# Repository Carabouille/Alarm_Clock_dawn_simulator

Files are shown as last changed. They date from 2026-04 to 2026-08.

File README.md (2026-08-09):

# Alarm_Clock_dawn_simulator
Hello, I'm Carabouille, a French guy who loves tech and hardware, and this is my GitHub to present you my project for Fallout!
I'm gonna present you my alarm clock with dawn simulator feature!

AND see just how beautiful it is !!! Yeah I know I did a great job you can tell me ^^

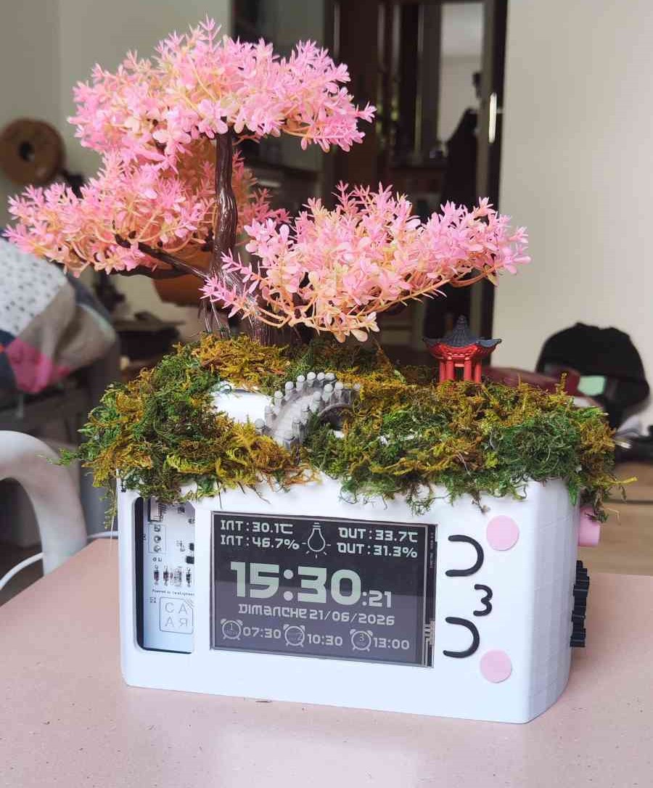
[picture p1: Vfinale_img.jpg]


And to see how it works in details you can watch the video that I did on my alarm clock : (CLICK ON MY AWESOME FACE !)

Clicl here ! (https://youtube.com/shorts/Zd3teZ0syxg)

# The idea 
I often have trouble waking up with my phone alarm. I often feel that I'm tired even though I slept a lot. And this is for a very simple reason: our brain is not a machine, he can't wake up so fast. He works on cycles. And our phone alarm gets him off very fast during this cycle. A better way to wake up more naturally is with the solar light (but the night I close the rolling shutter for the cold). So a solution to this issue is to use an alarm clocker with a dawn simulator feature to increase the brightness of the room over time to wake up your brain gently, but problem : Tis type of alarm clocks is really expensive (over 100 euros), so I told myself that it is the perfect occasion to create my own ALARM CLOCKS WITH A DAWN SIMULATOR!!! And I'm gonna add a lot of features like: 
- local weather
- Indoor temperature / humidity
- Bedside lamp (to read the night)
- Control all the Leds in my bedroom
- and more.....

I really can't wait to build my project, develop my skills and learn so much! I'm gonna give the best version of myself to be proud of my alarm clocks and I also hope that I will have the chance to go to Shenzen to meet other hardware fans! Kind regards, your French friend, Florian "Carabouille" CHARLES :))

# Zine page 
The better way to describe my project is with a poster who talks about it! 
I'm not a good designer, but I think that I made a good poster

ET VOILA : 

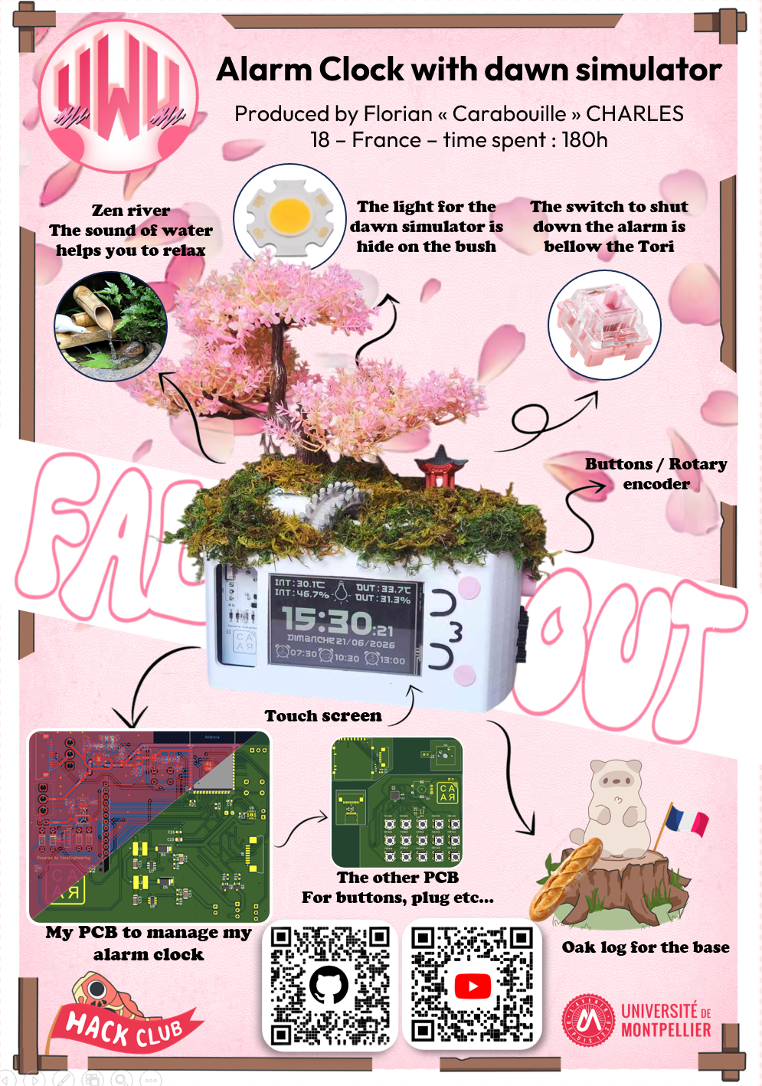
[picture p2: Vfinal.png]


The design idea is pretty simple: the alarm clock in the center and some arrows to explain the different parts of the project
I explain here 7 features: 
- The oak log for the base
- All the PCBs
- The touch screen
- The Zen river
- The light for the dawn simulator feature
- The switch on the top
- And the switches and the knob on the side

My favourite color is the pink (hard to guess ^^)
I really love the cherry flower in the background that reminds me of the cherry tree on the top of the alarm.
The UwU logo is everywhere cause with my friends it's a private joke since a few years.
I love the way that the "Fallout" goes behind the box.

Is not perfect of course but for my light skills in design I think it's really nice, I'm proud of it ! 

# CAD 
One of the main parts of my project is the CAD!
For this I used the software Solidworks ( a French soft! COCORICO!)
I'm in a toxic relationship with Solidworks, sometimes I love it, sometimes I hate it...
This software is not easy to use but after some crashes and bugs I finally made a CAD which I'm proud of

So for my project I had to work within certain constraints 

- a specific screen size
- a way to diffuse the light
- a heat sink for the light
- some buttons
- a battery
- a speaker
- a hole for the USB C port

And with all that, I need to find a good idea for design

My first idea was a shape like the giant telescope, like we can see in the American desert.
But I have never obtained a result that I like

So I completely changed my idea to have a Zen garden on the top of my alarm clock
With a tree, plants, and a river!

It looks like this : 

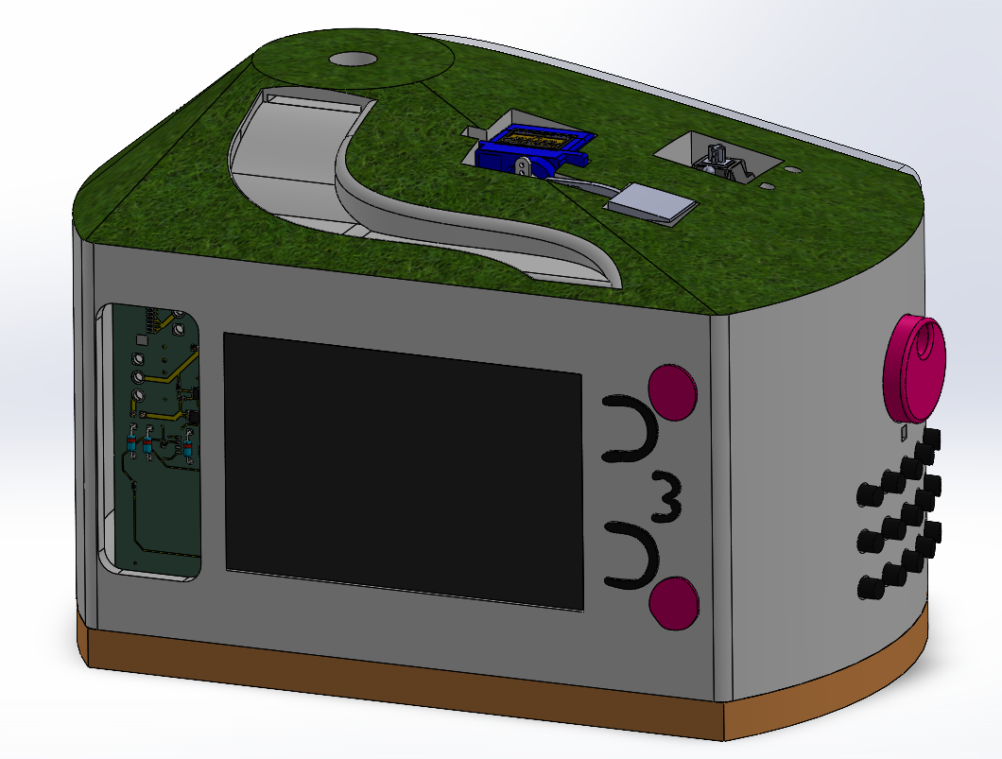
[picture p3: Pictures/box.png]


yes that is not the same as on the zine page,
Solidworks is not really good at rendering

But all the parts are here and I even find it cool! 
I really love that the PCB is not hidden by all the cases, it's cool to see it

On this picture we can see : the screen, the PCB, the UwU logo, the oak log and the buttons on the side

If we move to the top we can see the Zen garden 

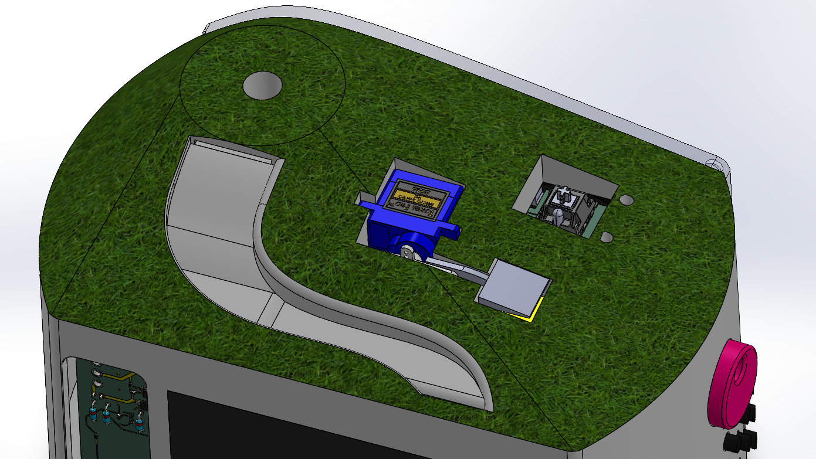
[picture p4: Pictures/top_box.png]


We can see :
- The hole on the top, for the cherry tree
- The river on the front
- The switch to shut down the alarm
- The green is for the artificial moss
- and the servo motor

The servo motor is here to hide the light during the day with moss on it. And when is it the time to turn the light on the servo motor move the piece of plastic with moss on it that hides the light to let the light illuminate the room.
So the light system is invisible during the day!

The servo motor is not hidden by the case cause the moss will recover it.

And on the switch I'll put a little Japanese temple like we can see on the poster.

Let's make the walls transparent to see what is inside the box!

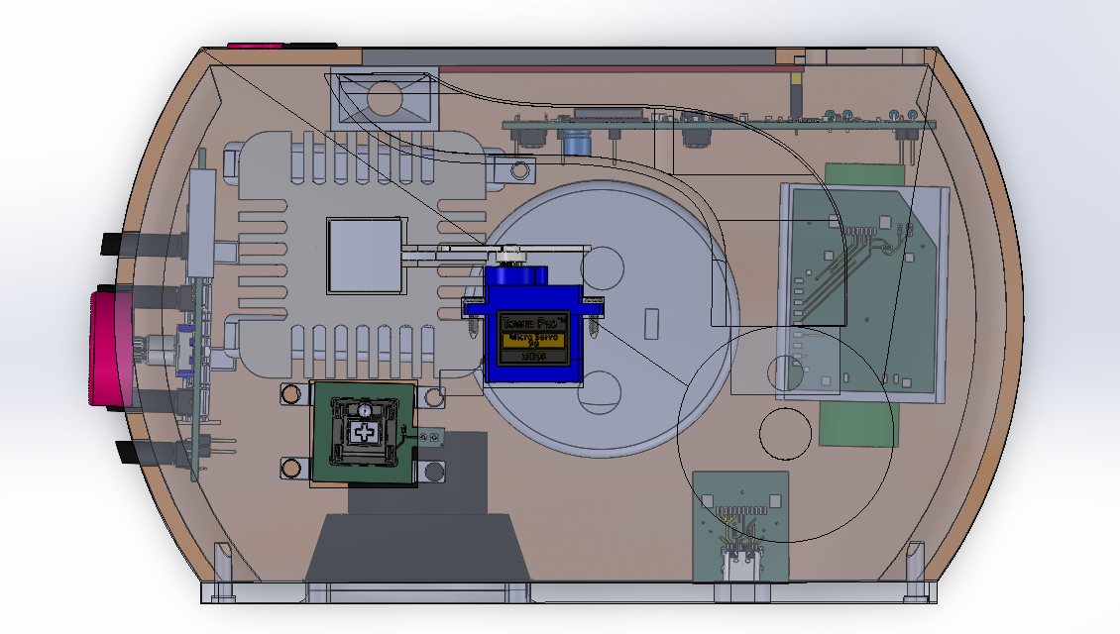
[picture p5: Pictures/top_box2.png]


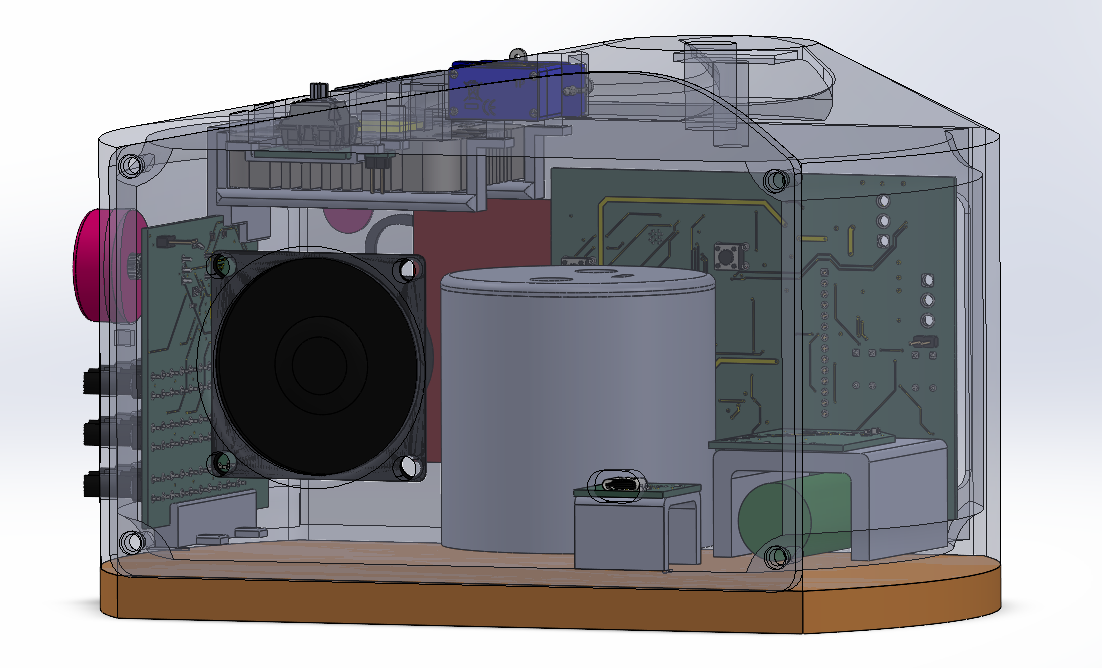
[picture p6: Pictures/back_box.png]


Yes, there are a lot of things inside it! 

We can see well in the first picture the servo motor as we saw earlier
And the light with the heat sink, which is carried by a support with screws to the box
The heat sink is necessary here cause the light needs to be at least a 8W to diffuse a minimum of the light to wake you. 
But the light is also powered on 24V and if you do the calcul

P = U * I

I = P / U

I = 8 / 24 = 0,33 A 

It's a lot for a little LED COB ! It can heat up to more than 100 degrees. With the heat sink, everything will be ok!

If we watch the second picture we can see the other components

Like the speaker, even if the light is supposed to wake you. If you sleep very deeply, good music is necessary to wake up! 
We can see on the left the PCB buttons for all the buttons and the knob. Is linked with the main PCB with a FPC cable.

The huge tank in the middle is for the water of the river. The pump is also inside. The holes are for the pipes.

We can see the USB C port in the bottom right also linked with the main PCB with a FPC cable.

On the right we have the PCB for the SD card. And below it we have our battery.
The battery is just in case that there is a power cut at home, the battery will supply the system until the return of power !

And that's already a lot for a CAD, but I'm really proud of me! I can't wait to print it!

# PCB

OK so now it's the moment to talk about my PCB! And it's a huge part of my project! 
It's only my second PCB so it's not perfect, the first was the macropad.

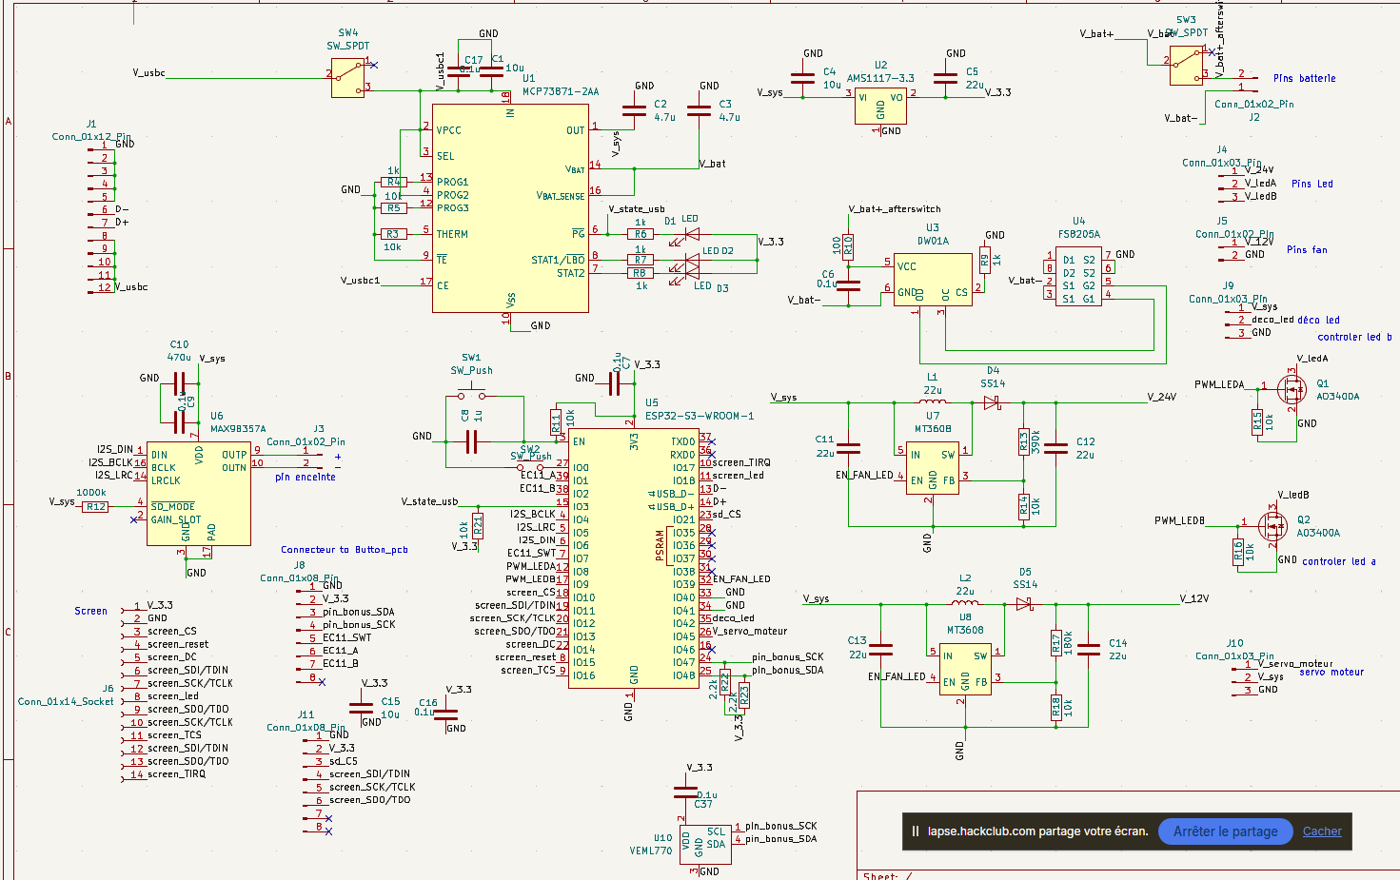
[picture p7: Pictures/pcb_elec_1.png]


This is only the main PCB, and I'm going to describe all the different parts
I'm not gonna describe how I chose the components because it's not really important, but for each component I had to follow the datasheet.

So we can see at the top left the port J1 that brings the power supply from the USB C port on an other PCB.
The power is sent to the first components the MCP73871. This component charge at the same time the battery in 4,2V and supplies the system with the 5V

But 5V is too high for an ESP32, so we need to decrease it to 3,3V with the AMS1117-3.3.

For this project I used an ESP32-S3-WROOM-1 that is very powerful and the WiFi connection will help me to search for the local weather.

For the speaker, we need to use an audio amplifier. I chose to use the MAX98357A, which is very famous for this type of project

I used a DW01A and a FS8205A, this duo of components is for the battery. To avoid overload, deep discharge, and protection from the short circuit.

For the LED and the fan of the heat sink I need 24V and 12V. So I used a 2 MT3608 to increase the voltage.

To control the led I'll use 2 channels of PWM to manage the warm and cold colors of the led.
To do this I'm gonna use a 2 transistors A03400A.

I also use a VEML770 a light sensor to manage the luminosity of the screen.

We also have a lot of connectors for the : 
- Screen
- USB C
- Heat sink
- Led COB
- Led strip (to decorate)
- servo motor
- SD card PCB
- Buttons PCB
- Battery

You can see two footprint for a switch (SW3 & SW4), if you wish to switch off the main power supply or just the battery power supply (!YOU NEED TO PLACE IT ! else the circuit is open)

And after having done the wiring diagram, it's time to root all the components between them! 

This is my final solution:

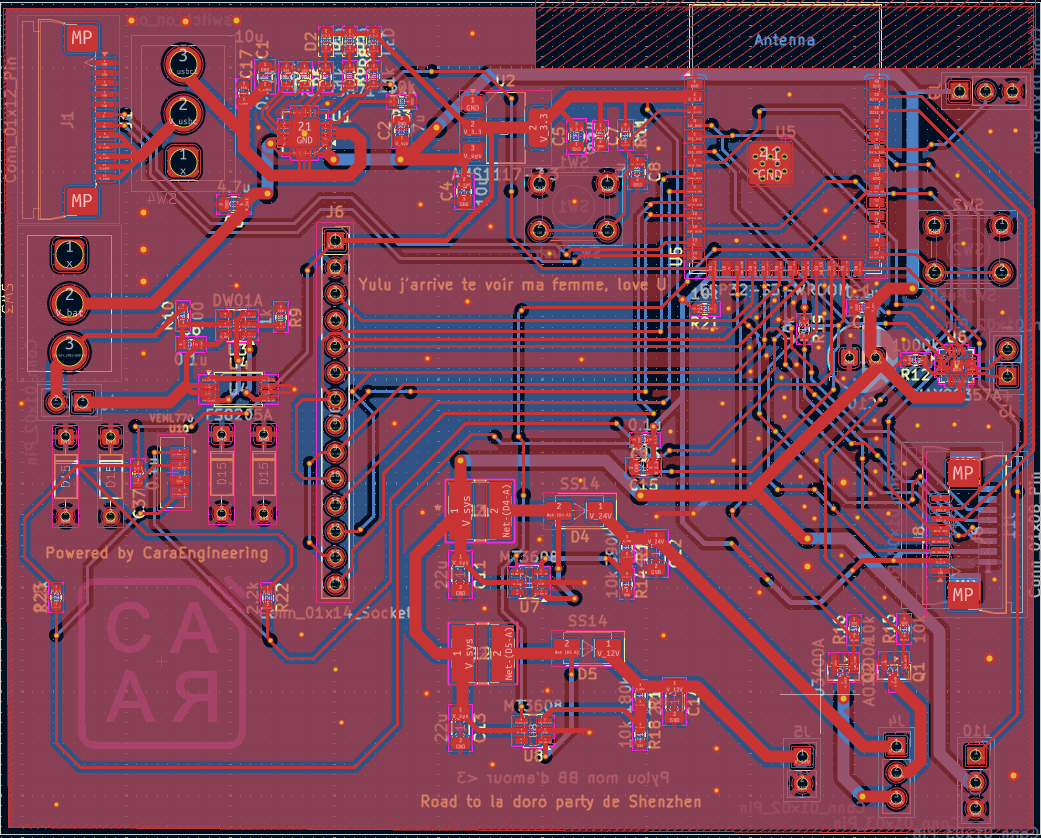
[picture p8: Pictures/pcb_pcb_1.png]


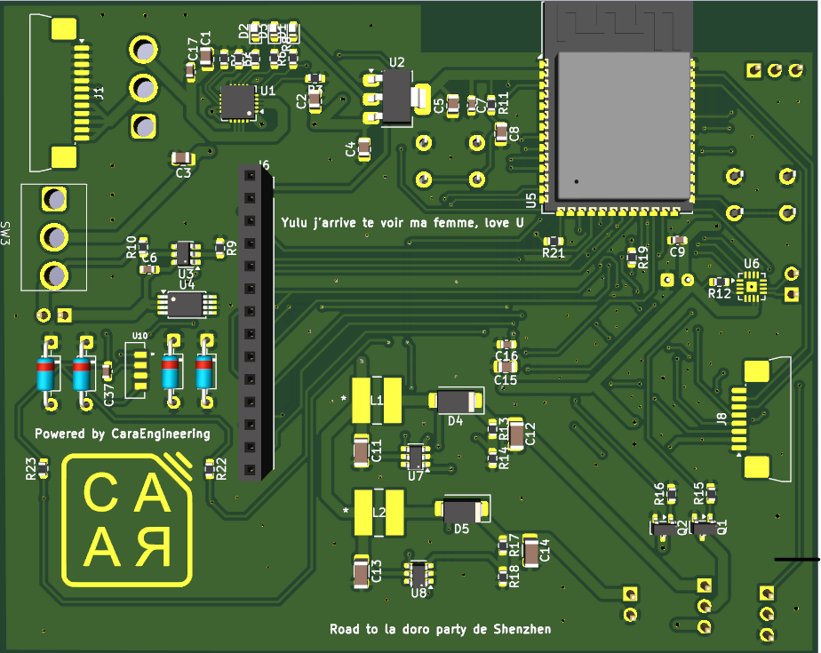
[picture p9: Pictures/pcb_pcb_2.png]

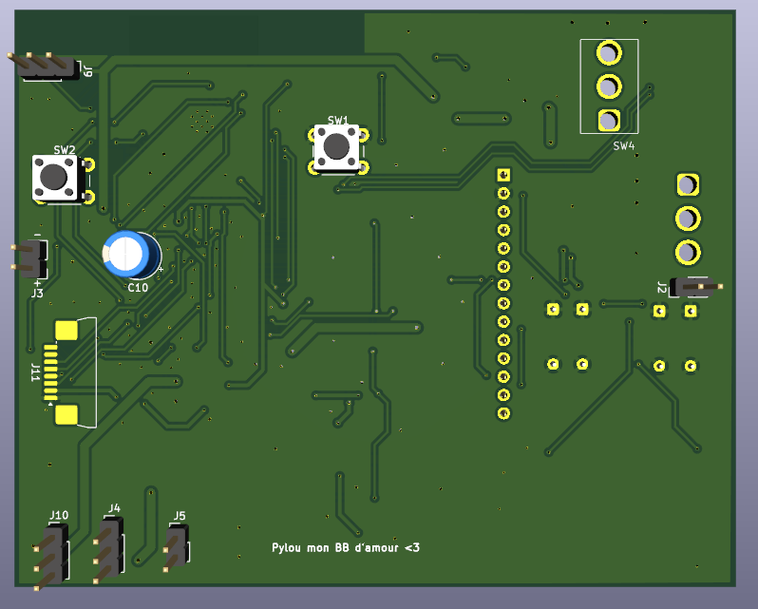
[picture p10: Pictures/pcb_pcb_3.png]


We can see here all the components which I mentioned earlier
I root on 2 faces so it's not too difficult to do it. The main difficulty is to match the footprint with the real component.

And that's all for the main PCB. It's already a lot!

Let's talk about the second PCB, The Buttons PCB!! 

This PCB is simpler than the previous one, it is just a little repetitive with all the buttons 
We can see here the wiring diagram!

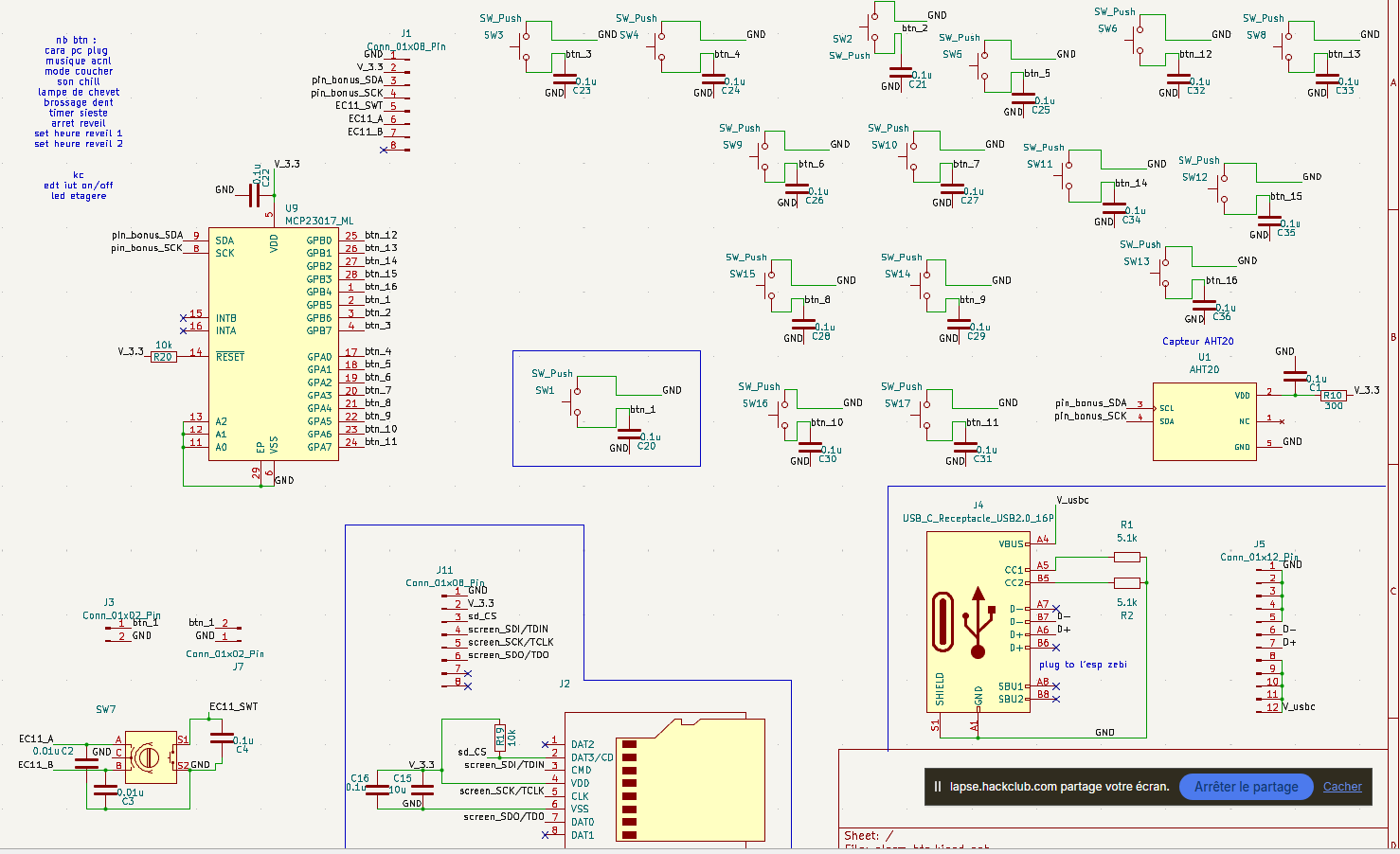
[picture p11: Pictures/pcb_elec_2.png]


You can see here 4 different PCBs separated by the blue lines.
The larger is the PCB with all the buttons and the polar.
Also, I used a MCP23017 to increase the number of pins GPIO of the ESP32 ( I used a lot of buttons ^^) I'll go into detail in the firmware part. 
You can see a capacitor in parallel for each button. It's anti-bounce material. It's very important for a professional project!
I added on this PCB an AHT 20, it's a temperature and humidity sensor.

The little PCB in the middle is for the switch on the top of the box.

The PCB on the bottom is the micro SD port card PCB

and the last is the PCB for the USB C

And after this it's rooting time ! 

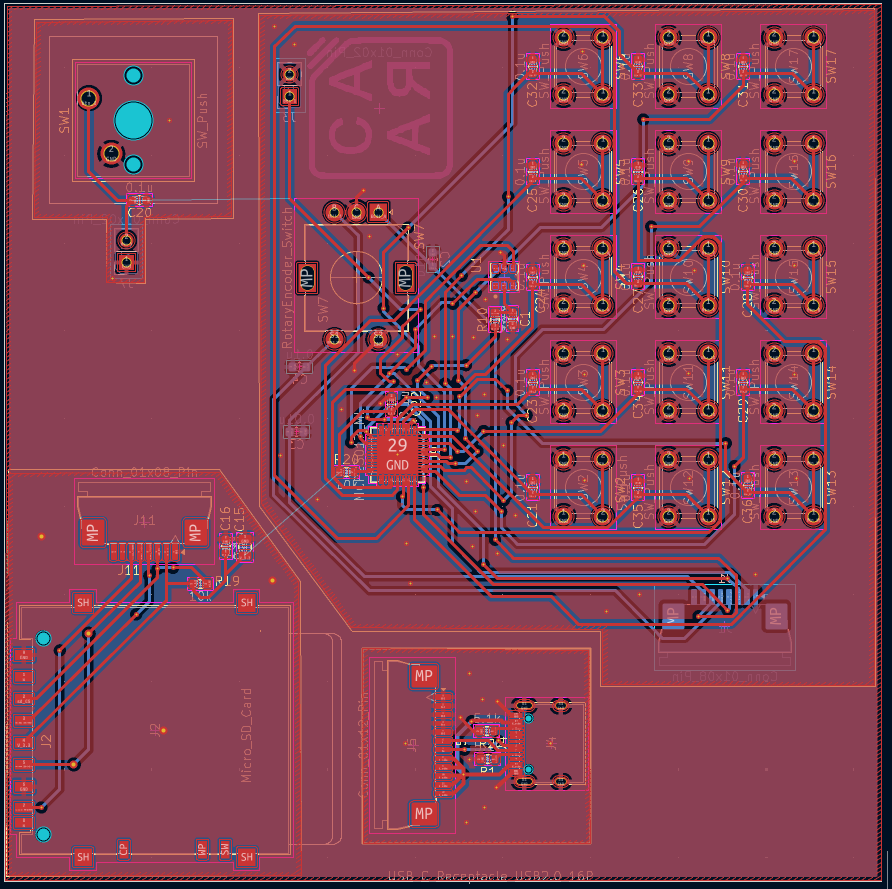
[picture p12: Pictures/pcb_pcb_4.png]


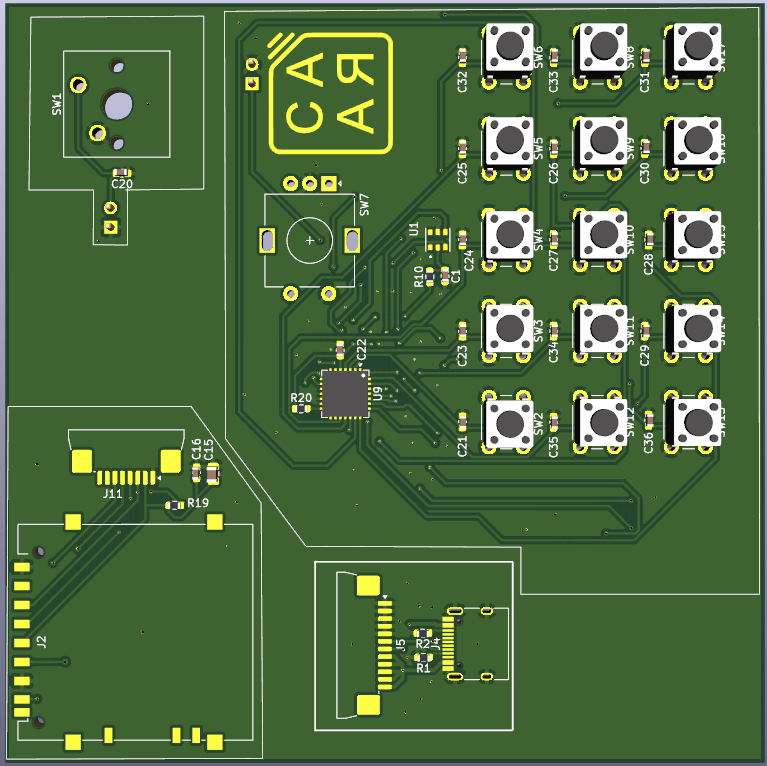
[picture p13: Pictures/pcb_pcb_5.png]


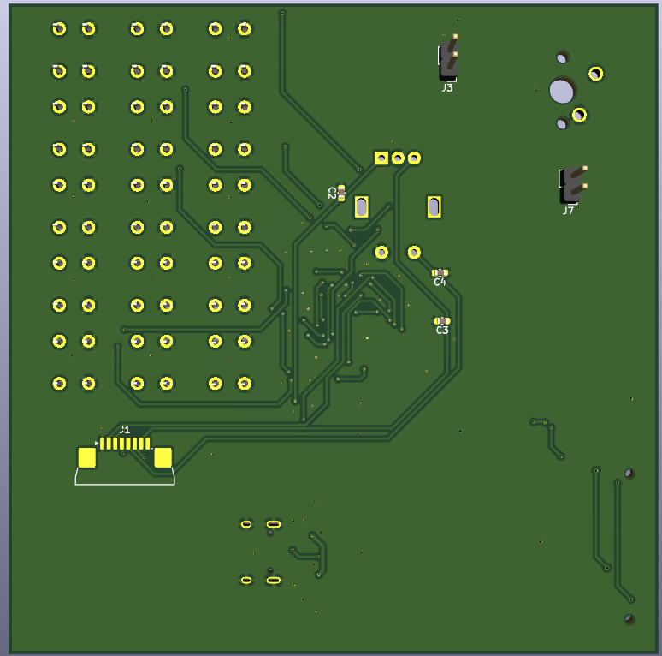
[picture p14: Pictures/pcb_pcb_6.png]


That wasn't possible with the dimensions I needed to avoid the waste of some part of the PCB, like you can see the part not used.
I'm gonna cut the different PCB myself with a dremel.

# Firmware
The Firmware is a big part of my project! (I said it for each part ;-;)
To code I used the software Visual Studio Code and the extension Plateformio
The code is pretty simple for the moment. I only initialize all the components. I'm gonna add all the interesting features when I could have the card in my hands.
For the moment, given that I only initialize the components, all my code parts are just from the example code that I found online and from old code that I made.

In the code I initialize :
- The I2C bus
- The audio amplifier
- The SD card
- The screen
- The wifi connection (to obtain the hour, date and more soon)
- All the buttons with the MCP23017
- Servo motor
- the EC11
- The signal PWM for the LED
- The dislay of the hours on the screen
- The enable pin for the MT3608
- The VEML7700
- The AHT20

There are still a lot of things to add. I will add this later (with components in front of me) cause it is code more complicated, and it's useless to code this without debugging in live (I guess)

The things that I need to add: 
- A good design of the hours, temperatures, etc...
- alarm features (with the dawn simulator)
- all the buttons feature like :
- - turn on the smart plug of my computer
  - play a ACNL music
  - a sleep mode
  - song chill
  - bedside lamp
  - nap timer
  - switch that shuts down the alarm
  - set alarm 1
  - set alarm 2
  - turn on the leds of my room
  - turn on the river
  - the other buttons will be there to adjust certain settings

# BOM

Now it's the time to do the BOM and order all our components! 

I mainly used this site : 

- https://www.lcsc.com/ for the components CMD
- https://www.aliexpress.com for some electronics and decoration
- https://jlcpcb.com for the PCB

I split the BOM into different parts.

The first part is the components that I'm going to order on LCSC (Overall, these are the CMD components)

| Components LCSC : | name | value | Quantity | LCSC code / link | price (€) | |
|---|---|---|---|---|---|---|
| | Resistance | 100 | 1 | [C105588](https://www.lcsc.com/product-detail/C105588.html) | 0.13 | X |
| | | 300 | 1 | [C2930092](https://www.lcsc.com/product-detail/C2930092.html) | 0.12 | X |
| | | 5,1k | 2 | [C2907044](https://www.lcsc.com/product-detail/C2907044.html) | 0.11 | X |
| | | 1M | 1 | [C2907115](https://www.lcsc.com/product-detail/C2907115.html) | 0.08 | X |
| | | 10k | 11 | [C98220](https://www.lcsc.com/product-detail/C98220.html) | 0.28 | X |
| | | 180k | 1 | [C2906999](https://www.lcsc.com/product-detail/C2906999.html) | 0.1 | X |
| | | 1k | 5 | [C22548](https://www.lcsc.com/product-detail/C22548.html) | 0.14 | X |
| | | 390k | 1 | [C137735](https://www.lcsc.com/product-detail/C137735) | 0.15 | X |
| | | 2,2k | 2 | [C4190](https://www.lcsc.com/product-detail/C4190.html) | 0.14 | X |
| | Capacitor | 10n | 2 | [C100042](https://www.lcsc.com/product-detail/C100042.html) | 0.23 | X |
| | | 100n | 26 | [C14663](https://www.lcsc.com/product-detail/C14663.html) | 0.56 | X |
| | | 10u | 4 | [C440198](https://www.lcsc.com/product-detail/C440198.html) | 1.27 | X |
| | | 1u | 1 | [C28323](https://www.lcsc.com/product-detail/C28323.html) | 0.24 | X |
| | | 22u | 5 | [C342620](https://www.lcsc.com/product-detail/C342620.html) | 2.1 | X |
| | | 4,7u | 2 | [C98192](https://www.lcsc.com/product-detail/C98192.html) | 0.18 | X |
| | VEML7700-TT | X | 1 | [C1850416](https://www.lcsc.com/product-detail/C1850416.html) | 1.49 | X |
| | FS8205A | X | 1 | [C2830320](https://www.lcsc.com/product-detail/C2830320.html) | 0.52 | X |
| | YLED0603B (led) | Blue | 1 | [C19171394](https://www.lcsc.com/product-detail/C19171394.html) | 0.54 | X |
| | YLED0603G (led) | Green | 1 | [C19273151](https://www.lcsc.com/product-detail/C19273151.html) | 0.54 | X |
| | KT-0603R (led) | Red | 1 | [C2286](https://www.lcsc.com/product-detail/C2286.html) | 0.59 | X |
| | MAX98357AETE+T | X | 1 | [C910544](https://www.lcsc.com/product-detail/C910544.html) | 1.24 | X |
| | MCP73871-2AAI/ML | X | 1 | [C144351](https://www.lcsc.com/product-detail/C144351.html) | 2.74 | X |
| | MT3608 | X | 2 | [C84817](https://www.lcsc.com/product-detail/C84817.html) | 0.69 | X |
| | SS14 (diode) | X | 2 | [C2837270](https://www.lcsc.com/product-detail/C2837270.html) | 0.48 | X |
| | AHT20 | X | 1 | [C2757850](https://www.lcsc.com/product-detail/C2757850.html) | 0.58 | X |
| | MCP23017T-E/ML | X | 1 | [C629439](https://www.lcsc.com/product-detail/C629439.html) | 1.46 | X |
| | micro sd card port | X | 1 | [C506790](https://www.lcsc.com/product-detail/C506790.html) | 3.66 | X |
| | USB-C port | X | 1 | [C2765186](https://www.lcsc.com/product-detail/C2765186.html) | 1.17 | X |
| | DW01A | X | 1 | [C351410](https://www.lcsc.com/product-detail/C351410.html) | 0.75 | X |
| | Coil | 22u | 2 | [C2826664](https://www.lcsc.com/product-detail/C2826664.html) | 0.64 | X |
| | AMS1117-3.3 | X | 1 | [C6186](https://www.lcsc.com/product-detail/C6186.html) | 0.99 | X |
| | AO3400A | X | 2 | [C20917](https://www.lcsc.com/product-detail/C20917.html) | 0.36 | X |
| | FFC / FPC connector 1mm | 8 pins | 4 | [C262714](https://www.lcsc.com/product-detail/C262714.html) | 0.99 | X |
| | | 12 pins | 2 | [C262718](https://www.lcsc.com/product-detail/C262718.html) | 1.1 | X |
| | ESP32-S3-WROOM-1 | X | 1 | [C2913202](https://www.lcsc.com/product-detail/C2913202.html) | 4.58 | X |
| Total | | | | | 30.94 | |
| | | | | | | |

The second part is for the other types of components like switch, pump, speaker, LED, etc...
For the moment, it's only electronic components, all buy in Aliexpress

| Components | name | value | Quantity | LCSC code / link | price (€) | |
|---|---|---|---|---|---|---|
| Others components (not in LCSC) | Switch push buttons | 6mm.6mm.5.5mm | 17 | [Link](https://fr.aliexpress.com/item/1005001629177989.html) | 1.22 | |
| | EC11 rotary encoder | X | 1 | [Link](https://fr.aliexpress.com/item/1005003824684681.html) | 1.33 | |
| | Touch screen | 4 inch | 1 | [Link](https://fr.aliexpress.com/item/1005005791515997.html) | 14.39 | |
| | Speaker | 8 ohm | 1 | [Link](https://fr.aliexpress.com/item/4000034945525.html) | 10.7 | |
| | keyboard switch | X | 1 | [Link](https://fr.aliexpress.com/item/1005006298192363.html) | 4.39 | |
| | Servo motor | 180 degrees | 1 | [Link](https://fr.aliexpress.com/item/1005006572297006.html) | 2.7 | |
| | LED COB | 24V 8W | 1 | [Link](https://fr.aliexpress.com/item/1005006373977700.html) | 1.89 | X |
| | Heat sink | with fan 12V | 1 | [Link](https://fr.aliexpress.com/item/1005003605697738.html) | 3.19 | |
| | Male pins | 17 pins | 1 | [Link](https://fr.aliexpress.com/item/4000873858801.html) | 1.89 | X |
| | Female pins | 14 pins | 1 | | | X |
| | Battery | 18650 | 1 | [Link](https://fr.aliexpress.com/item/1005008704468583.html) | 6.59 | |
| | Led strip | addressable 1m  | 1 | [Link](https://fr.aliexpress.com/item/1005009613294814.html) | 4.99 | |
| | 3D-printed insert | M3 | 12 | [Link](https://fr.aliexpress.com/item/1005007653131713.html) | 1.69 | |
| | Screw | M3 | 12 | [Link](https://fr.aliexpress.com/item/32968616563.html) | 1.4 | |
| | Micro SD card | 4go | 1 | [Link](https://fr.aliexpress.com/item/1005008059516973.html) | 3.29 | |
| | FPC cable | 12pins 15cm 1mm | 1 | [Link](https://fr.aliexpress.com/item/1005007561337665.html) | 1.72 | X |
| | | 8pins 10cm 1mm  | 2 | [Link](https://fr.aliexpress.com/item/1005007561337665.html) | 2.18 | X |
| | epoxy resin | 50ml + 50ml | 1 | [Link](https://fr.aliexpress.com/item/1005007345256355.html) | 6.59 | X |
| | Water pump | 5V | 1 | [Link](https://fr.aliexpress.com/item/1005006614378374.html) | 1.69 | X |
| | Pipe | 1m | 1 | [Link](https://fr.aliexpress.com/item/1005006614378374.html) | 1.81 | X |
| | Switch | ON OFF ON | 2 | [Link](https://fr.aliexpress.com/item/1005002461701337.html) | 2.4 | |
| Total | | | | | 73.65 | |
| | | | | | | |

In this last part we have the PCB, and all the elements of decoration 

| Components | name | value | Quantity | LCSC code / link | price (€) | |
|---|---|---|---|---|---|---|
| PCB (JLCPCB) | Main PCB | X | 1 | Upload GERBER on JLCPCB | 3.4 | X |
| | Buttons PCB | X | 1 | | 3.4 |  X |
| | | | | | | |
| Décoration | Log (for the base) | 14-16cm | 2 | [Link](https://fr.aliexpress.com/item/1005007635992230.html) | 9.78 | X |
| | Temple | X | 1 | [Link](https://fr.aliexpress.com/item/1005007500230985.html) | 2.1 | X |
| | Moss 1 | 20g | 1 | [Link](https://fr.aliexpress.com/item/1005005026348059.html) | 1.72 | X |
| | Moss 2 | 20g | 1 | [Link](https://fr.aliexpress.com/item/1005005026348059.html) | 2.04 | X |
| | Cherry tree | X | 1 | [Link](https://fr.aliexpress.com/item/1005003593401791.html) | 3.89 | X |
| | PLA black + white | 1kg + 1kg | 1 | [Link](https://www.amazon.fr/gp/product/B0CV4V5L7T/ref=ewc_pr_img_1?smid=AKWYTSYUMR87P&th=1) | 20.12 | X |
| | Bridge | X | 1 | [Link](https://fr.aliexpress.com/item/1005003493992894.html) | 1.05 | X |
| Total | | | | | 42.7 | |
| | | | | | | |
| | | | | | | |
| Full price | 153.94 | | | | | |

So the total for all this is 153,94€ (180,55$)

# Build it ! 

To build this you first need to order all the components that you need. 

After this it's time to print the box and all the others parts who are in the STL file. For the color : withe for the box, black for the buttons and the UwU eyes and pink for the knob et the UwU cheeks. for the support inside the box it's doesn't matter.

You need to apply the epoxy resin on all the surfaces in direct contact with the water (like the river and the tank)

Glue the log on the underside of the box 

You need to solder all the components on the pcb (following the wiring diagram (view it on the kicad files)), and solder the external components (like the speaker, battery, etc) 

Upload the code on the ESP32.

Following that you need to setup all the components inside the box like the CAD 



Holes are here to support the support of the switch and the heat sink on the top of the box with screw M3.

Place all the decoration elements on the top (like the moss, the tree, the temple, etc..)

And after that You need to setup the timer of the alamr clock and that's ALL ! 

# Special thanks

I want to thank my friend Pylou (love u my boy) for introducing me to the project !!

thanks to the HackClub / Fallout community the goatest community 

thanks to my mum for creating me

Thanks to photosynthesis for creating the oxygen that I breathe

Thanks to the reviewer !! I know the project is not easy to understand ;-; 

Thanks to Soup for the free koi with the streak ! 

I really hope you will enjoy it !

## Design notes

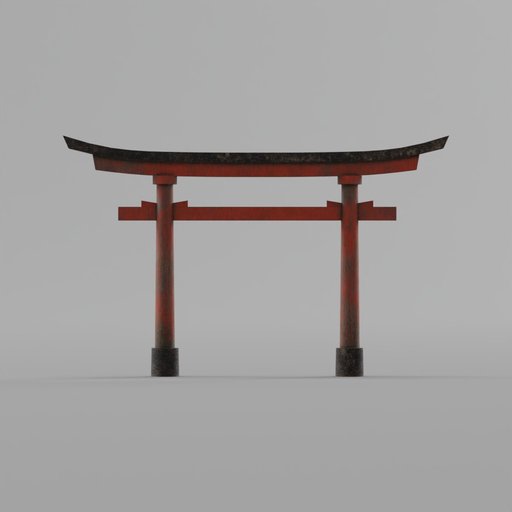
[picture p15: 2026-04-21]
blender/blender_projet/assets/models/torii-gate_03c77e5a-83a8-4e07-8661-758e4e9ec7ad/preview.png

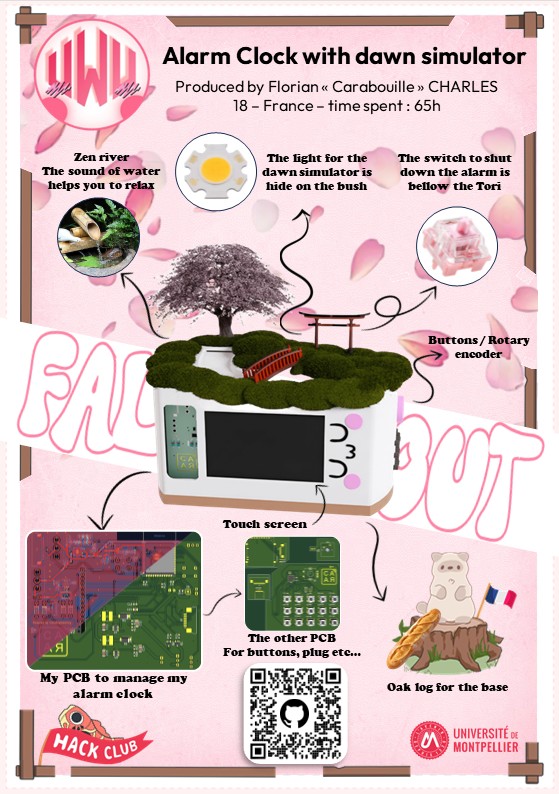
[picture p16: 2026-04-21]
Pictures/Zine_page_pic.jpg

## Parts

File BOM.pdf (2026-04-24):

Components LCSC : | name | value
Resistance | 100
| 300
| 5,1k
| 1M
| 10k
| 180k
| 1k
| 390k
| 2,2k
Capacitor | 10n
| 100n
| 10u
| 1u
| 22u
| 4,7u
VEML7700-TT | X
FS8205A | X
YLED0603B (led) | Blue
YLED0603G (led) | Green
KT-0603R (led) | Red
MAX98357AETE+T | X
MCP73871-2AAI/ML | X
MT3608 | X
SS14 (diode) | X
AHT20 | X
MCP23017T-E/ML | X
micro sd card port | X
USB-C port | X
DW01A | X
Coil | 22u
AMS1117-3.3 | X
AO3400A | X
FFC / FPC connector 1mm | 8 pins
| 12 pins
ESP32-S3-WROOM-1 | X
Others components (not in LCSC) | Switch push buttons | 6mm.6mm.5.5mm
EC11 rotary encoder | X
Touch screen | 4 inch
Speaker | 8 ohm
keyboard switch | X
Servo motor | 180 degrees
LED COB | 24V 8W
Heat sink | with fan 12V
Male pins | 17 pins
Female pins | 14 pins
Battery | 18650
Led strip | addressable 1m

3D-printed insert | M3
Screw | M3
Micro SD card | 4go
FPC cable | 12pins 15cm 1mm
8pins 10cm 1mm
epoxy resin | 50ml + 50ml
Water pump | 5V
Pipe | 1m
PCB (JLCPCB) | Main PCB | X
| Buttons PCB | X
Décoration | Log (for the base) | 14-16cm
Temple | X
Moss 1 | 20g
Moss 2 | 20g
Cherry tree | X
PLA black + white | 1kg + 1kg
Bridge | X
Full price | 150,39
Real price | 94,51
Aliexpress | 38,35
LCSC | 30,94
Amazon | 20,12
JLCPCB | 5,1

Quantity | LCSC code / link | price (€)
1 | C105588 (https://www.lcsc.com/product-detail/C105588.html?s_z=n_q_C105588) | 0,13
1 | C2930092 (https://www.lcsc.com/product-detail/C2930092.html?s_z=n_q_C2930092) | 0,12
2 | C2907044 (https://www.lcsc.com/product-detail/C2907044.html?s_z=n_q_C2907044) | 0,11
1 | C2907115 (https://www.lcsc.com/product-detail/C2907115.html?s_z=n_q_C2907115) | 0,08
11 | C98220 (https://www.lcsc.com/product-detail/C98220.html?s_z=n_q_C98220) | 0,28
1 | C2906999 (https://www.lcsc.com/product-detail/C2906999.html?s_z=n_q_C2906999) | 0,1
5 | C22548 (https://www.lcsc.com/product-detail/C22548.html?s_z=n_q_C22548) | 0,14
1 | C137735 (https://www.lcsc.com/product-detail/C137735.html?s_z=n_q_C137735) | 0,15
2 | C4190 (https://www.lcsc.com/product-detail/C4190.html?s_z=n_q_C4190) | 0,14
2 | C100042 (https://www.lcsc.com/product-detail/C100042.html?s_z=n_q_C100042) | 0,23
26 | C14663 (https://www.lcsc.com/product-detail/C14663.html?s_z=n_q_C14663) | 0,56
4 | C440198 (https://www.lcsc.com/product-detail/C440198.html?s_z=n_q_C440198) | 1,27
1 | C28323 (https://www.lcsc.com/product-detail/C28323.html?s_z=n_q_C28323) | 0,24
5 | C342620 (https://www.lcsc.com/product-detail/C342620.html?s_z=n_q_C342620) | 2,1
2 | C98192 (https://www.lcsc.com/product-detail/C98192.html?s_z=n_q_C98192) | 0,18
1 | C1850416 (https://www.lcsc.com/product-detail/C1850416.html?s_z=n_q_C1850416) | 1,49
1 | C2830320 (https://www.lcsc.com/product-detail/C2830320.html?s_z=n_q_C2830320) | 0,52
1 | C19171394 (https://www.lcsc.com/product-detail/C19171394.html?s_z=n_q_C19171394) | 0,54
1 | C19273151 (https://www.lcsc.com/product-detail/C19273151.html?s_z=n_q_C19273151) | 0,54
1 | C2286 (https://www.lcsc.com/product-detail/C2286.html?s_z=n_q_C2286) | 0,59
1 | C910544 (https://www.lcsc.com/product-detail/C910544.html?s_z=n_q_C910544) | 1,24
1 | C144351 (https://www.lcsc.com/product-detail/C144351.html?s_z=n_q_C144351) | 2,74
2 | C84817 (https://www.lcsc.com/product-detail/C84817.html?s_z=n_q_C84817) | 0,69
2 | C2837270 (https://www.lcsc.com/product-detail/C2837270.html?s_z=n_q_C2837270) | 0,48
1 | C2757850 (https://www.lcsc.com/product-detail/C2757850.html?s_z=n_q_C2757850) | 0,58
1 | C629439 (https://www.lcsc.com/product-detail/C629439.html?s_z=n_q_C629439) | 1,46
1 | C506790 (https://www.lcsc.com/product-detail/C506790.html?s_z=n_q_C506790) | 3,66
1 | C2765186 (https://www.lcsc.com/product-detail/C2765186.html?s_z=n_q_C2765186) | 1,17
1 | C351410 (https://www.lcsc.com/product-detail/C351410.html?s_z=n_q_C351410) | 0,75
2 | C2826664 (https://www.lcsc.com/product-detail/C2826664.html?s_z=n_q_C2826664) | 0,64
1 | C6186 (https://www.lcsc.com/product-detail/C6186.html?s_z=n_q_C6186) | 0,99
2 | C20917 (https://www.lcsc.com/product-detail/C20917.html?s_z=n_q_C20917) | 0,36
4 | C262714 (https://www.lcsc.com/product-detail/C262714.html?s_z=n_q_C262714) | 0,99
2 | C262718 (https://www.lcsc.com/product-detail/C262718.html?s_z=n_q_C262718) | 1,1
1 | C2913202 (https://www.lcsc.com/product-detail/C2913202.html?s_z=n_q_C2913202) | 4,58
30,94
17 | Link (https://fr.aliexpress.com/item/1005001629177989.html) | 1,22
1 | Link (https://fr.aliexpress.com/item/1005003824684681.html) | 1,33
1 | Link (https://fr.aliexpress.com/item/1005005791515997.html) | 14,39
1 | Link (https://fr.aliexpress.com/item/4000034945525.html) | 10,7
1 | Link (https://fr.aliexpress.com/item/1005006298192363.html?curPageLogUid=gooq9QGv7BWw) | 4,39
1 | Link (https://fr.aliexpress.com/item/1005006572297006.html?curPageLogUid=upkbVzHBRk64) | 2,7
1 | Link (https://fr.aliexpress.com/item/1005006373977700.html) | 1,89
1 | Link (https://fr.aliexpress.com/item/1005003605697738.html) | 3,19
1 | Link (https://fr.aliexpress.com/item/4000873858801.html?mp=1) | 1,89
1
1 | Link (https://fr.aliexpress.com/item/1005008704468583.html?curPageLogUid=UXVh5AwultNA) | 6,59
1 | Link (https://fr.aliexpress.com/item/1005009613294814.html?curPageLogUid=OopZgshG9YMS) | 4,99

12 | Link (https://fr.aliexpress.com/item/1005007653131713.html?curPageLogUid=Q60nQoBk4Yrg) | 1,69
12 | Link (https://fr.aliexpress.com/item/32968616563.html?curPageLogUid=VC2mM7krZnQV) | 1,4
1 | Link (https://fr.aliexpress.com/item/1005008059516973.html?curPageLogUid=3sIpPzvfLVUV) | 3,29
1 | Link (https://fr.aliexpress.com/item/1005007561337665.html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) | 1,72
2 | Link (https://fr.aliexpress.com/item/1005007561337665.html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) | 2,18
1 | Link (https://fr.aliexpress.com/item/1005007345256355.html?curPageLogUid=9vanx70l8WJk) | 6,59
1 | Link (https://fr.aliexpress.com/item/1005006614378374.html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) | 1,69
1 | Link (https://fr.aliexpress.com/item/1005006614378374.html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) | 1,81
73,65
1 | 1,7 | (I had a promo it's 3,4 instead)
1 | 3,4
2 | Link (https://fr.aliexpress.com/item/1005007635992230.html?mp=1) | 9,78
1 | Link (https://fr.aliexpress.com/item/1005007500230985.html?curPageLogUid=3TB0Xy0rew2e) | 2,1
1 | Link (https://fr.aliexpress.com/item/1005005026348059.html?curPageLogUid=WHp4W42rZr0k) | 1,72
1 | Link (https://fr.aliexpress.com/item/1005005026348059.html?curPageLogUid=WHp4W42rZr0k) | 2,04
1 | Link (https://fr.aliexpress.com/item/1005003593401791.html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) | 3,89
1 | Link (https://www.amazon.fr/gp/product/B0CV4V5L7T/ref=ewc_pr_img_1?smid=AKWYTSYUMR87P&th=1) | 20,12
1 | Link (https://fr.aliexpress.com/item/1005003493992894.html?curPageLogUid=BrLVJl9Xb5AY) | 1,05
40,7

Upload GERBER on JLCPCB

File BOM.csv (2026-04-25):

Components LCSC : | name | value | Quantity | LCSC code / link | price (€)
 | Resistance | 100 | 1 | C105588 | 0.13
 |  | 300 | 1 | C2930092 | 0.12
,,"5,1k",2,C2907044,0.11,
 |  | 1M | 1 | C2907115 | 0.08 | https://www.lcsc.com/product-detail/C2907044.html
 |  | 10k | 11 | C98220 | 0.28 | https://www.lcsc.com/product-detail/C2907115.html
 |  | 180k | 1 | C2906999 | 0.1 | https://www.lcsc.com/product-detail/C2906999.html?s_z=n_q_C2906999
 |  | 1k | 5 | C22548 | 0.14 | https://www.lcsc.com/product-detail/C22548.html?s_z=n_q_C22548
 |  | 390k | 1 | C137735 | 0.15 | https://www.lcsc.com/product-detail/C22548.html?s_z=n_q_C22548
,,"2,2k",2,C4190,0.14,https://www.lcsc.com/product-detail/C137735.html?s_z=n_q_C137735
 | Capacitor | 10n | 2 | C100042 | 0.23 | https://www.lcsc.com/product-detail/C4190.html?s_z=n_q_C4190
 |  | 100n | 26 | C14663 | 0.56 | https://www.lcsc.com/product-detail/C100042.html?s_z=n_q_C100042
 |  | 10u | 4 | C440198 | 1.27 | https://www.lcsc.com/product-detail/C14663.html?s_z=n_q_C14663
 |  | 1u | 1 | C28323 | 0.24 | https://www.lcsc.com/product-detail/C28323.html?s_z=n_q_C28323
 |  | 22u | 5 | C342620 | 2.1 | https://www.lcsc.com/product-detail/C342620.html?s_z=n_q_C342620
,,"4,7u",2,C98192,0.18,https://www.lcsc.com/product-detail/C98192.html?s_z=n_q_C98192
 | VEML7700-TT | X | 1 | C1850416 | 1.49 | https://www.lcsc.com/product-detail/C1850416.html?s_z=n_q_C1850416
 | FS8205A | X | 1 | C2830320 | 0.52 | https://www.lcsc.com/product-detail/C2830320.html?s_z=n_q_C2830320
 | YLED0603B (led) | Blue | 1 | C19171394 | 0.54 | https://www.lcsc.com/product-detail/C19171394.html?s_z=n_q_C19171394
 | YLED0603G (led) | Green | 1 | C19273151 | 0.54 | https://www.lcsc.com/product-detail/C19273151.html?s_z=n_q_C19273151
 | KT-0603R (led) | Red | 1 | C2286 | 0.59 | https://www.lcsc.com/product-detail/C2286.html?s_z=n_q_C2286
 | MAX98357AETE+T | X | 1 | C910544 | 1.24 | https://www.lcsc.com/product-detail/C910544.html?s_z=n_q_C910544
 | MCP73871-2AAI/ML | X | 1 | C144351 | 2.74 | https://www.lcsc.com/product-detail/C144351.html?s_z=n_q_C144351
 | MT3608 | X | 2 | C84817 | 0.69 | https://www.lcsc.com/product-detail/C84817.html?s_z=n_q_C84817
 | SS14 (diode) | X | 2 | C2837270 | 0.48 | https://www.lcsc.com/product-detail/C2837270.html?s_z=n_q_C2837270
 | AHT20 | X | 1 | C2757850 | 0.58 | https://www.lcsc.com/product-detail/C2757850.html?s_z=n_q_C2757850
 | MCP23017T-E/ML | X | 1 | C629439 | 1.46 | https://www.lcsc.com/product-detail/C629439.html?s_z=n_q_C629439
 | micro sd card port | X | 1 | C506790 | 3.66 | https://www.lcsc.com/product-detail/C2765186.html?s_z=n_q_C2765186
 | USB-C port | X | 1 | C2765186 | 1.17 | https://www.lcsc.com/product-detail/C2765186.html?s_z=n_q_C2765186
 | DW01A | X | 1 | C351410 | 0.75 | https://www.lcsc.com/product-detail/C351410.html?s_z=n_q_C351410
 | Coil | 22u | 2 | C2826664 | 0.64 | https://www.lcsc.com/product-detail/C2826664.html?s_z=n_q_C2826664
 | AMS1117-3.3 | X | 1 | C6186 | 0.99 | https://www.lcsc.com/product-detail/C6186.html?s_z=n_q_C6186
 | AO3400A | X | 2 | C20917 | 0.36 | https://www.lcsc.com/product-detail/C20917.html?s_z=n_q_C20917
 | FFC / FPC connector 1mm | 8 pins | 4 | C262714 | 0.99 | https://www.lcsc.com/product-detail/C262714.html?s_z=n_q_C262714
 |  | 12 pins | 2 | C262718 | 1.1 | https://www.lcsc.com/product-detail/C262718.html?s_z=n_q_C262718
 | ESP32-S3-WROOM-1 | X | 1 | C2913202 | 4.58 | https://www.lcsc.com/product-detail/C2913202.html?s_z=n_q_C2913202
 |  |  |  |  | 30.94
Others components (not in LCSC) | Switch push buttons | 6mm.6mm.5.5mm | 17 | Link | 1.22
 | EC11 rotary encoder | X | 1 | Link | 1.33 | https://fr.aliexpress.com/item/1005001629177989.html
 | Touch screen | 4 inch | 1 | Link | 14.39 | https://fr.aliexpress.com/item/1005006298192363.html?curPageLogUid=gooq9QGv7BWw
 | Speaker | 8 ohm | 1 | Link | 10.7 | https://fr.aliexpress.com/item/1005006298192363.html?curPageLogUid=gooq9QGv7BWw
 | keyboard switch | X | 1 | Link | 4.39 | https://fr.aliexpress.com/item/1005001629177989.html
 | Servo motor | 180 degrees | 1 | Link | 2.7 | https://fr.aliexpress.com/item/1005006298192363.html?curPageLogUid=gooq9QGv7BWw
 | LED COB | 24V 8W | 1 | Link | 1.89 | https://fr.aliexpress.com/item/1005006298192363.html?curPageLogUid=gooq9QGv7BWw
 | Heat sink | with fan 12V | 1 | Link | 3.19 | https://fr.aliexpress.com/item/1005003493992894.html?curPageLogUid=BrLVJl9Xb5AY
 | Male pins | 17 pins | 1 | Link | 1.89 | https://fr.aliexpress.com/item/1005001629177989.html
 | Female pins | 14 pins | 1 |  |  | https://fr.aliexpress.com/item/1005001629177989.html
 | Battery | 18650 | 1 | Link | 6.59 | https://fr.aliexpress.com/item/1005003493992894.html?curPageLogUid=BrLVJl9Xb5AY
 | Led strip | addressable 1m | 1 | Link | 4.99 | https://fr.aliexpress.com/item/1005005026348059.html?curPageLogUid=WHp4W42rZr0k
 | 3D-printed insert | M3 | 12 | Link | 1.69 | https://fr.aliexpress.com/item/1005005026348059.html?curPageLogUid=WHp4W42rZr0k
 | Screw | M3 | 12 | Link | 1.4 | https://fr.aliexpress.com/item/1005003493992894.html?curPageLogUid=BrLVJl9Xb5AY
 | Micro SD card | 4go | 1 | Link | 3.29 | https://fr.aliexpress.com/item/1005001629177989.html
 | FPC cable | 12pins 15cm 1mm | 1 | Link | 1.72 | https://fr.aliexpress.com/item/1005005026348059.html?curPageLogUid=WHp4W42rZr0k
 |  | 8pins 10cm 1mm | 2 | Link | 2.18 | https://fr.aliexpress.com/item/1005005026348059.html?curPageLogUid=WHp4W42rZr0k
 | epoxy resin | 50ml + 50ml | 1 | Link | 6.59 | https://fr.aliexpress.com/item/1005005026348059.html?curPageLogUid=WHp4W42rZr0k
 | Water pump | 5V | 1 | Link | 1.69 | https://fr.aliexpress.com/item/1005005026348059.html?curPageLogUid=WHp4W42rZr0k
 | Pipe | 1m | 1 | Link | 1.81 | https://fr.aliexpress.com/item/1005005026348059.html?curPageLogUid=WHp4W42rZr0k
 |  |  |  |  | 73.65
PCB (JLCPCB),Main PCB ,X,1,Upload GERBER on JLCPCB,1.7,"(I had a promo it's 3,4 instead)"
 | Buttons PCB | X | 1 |  | 3.4
Décoration | Log (for the base) | 14-16cm | 2 | Link | 9.78
 | Temple | X | 1 | Link | 2.1
 | Moss 1 | 20g | 1 | Link | 1.72
 | Moss 2 | 20g | 1 | Link | 2.04
 | Cherry tree | X | 1 | Link | 3.89
 | PLA black + white | 1kg + 1kg | 1 | Link | 20.12
 | Bridge | X | 1 | Link | 1.05
 |  |  |  |  | 40.7
Full price | 150.39
Real price | 94.51
Aliexpress | 38.35
LCSC | 30.94
Amazon | 20.12
JLCPCB | 5.1

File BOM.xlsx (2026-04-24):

Components LCSC : | name | value | Quantity | LCSC code / link | price (€)
 | Resistance | 100 | 1 | C105588 (https://www.lcsc.com/product-detail/C105588.html?s_z=n_q_C105588) | 0.13
 |  | 300 | 1 | C2930092 (https://www.lcsc.com/product-detail/C2930092.html?s_z=n_q_C2930092) | 0.12
 |  | 5,1k | 2 | C2907044 (https://www.lcsc.com/product-detail/C2907044.html?s_z=n_q_C2907044) | 0.11
 |  | 1M | 1 | C2907115 (https://www.lcsc.com/product-detail/C2907115.html?s_z=n_q_C2907115) | 0.08
 |  | 10k | 11 | C98220 (https://www.lcsc.com/product-detail/C98220.html?s_z=n_q_C98220) | 0.28
 |  | 180k | 1 | C2906999 (https://www.lcsc.com/product-detail/C2906999.html?s_z=n_q_C2906999) | 0.1
 |  | 1k | 5 | C22548 (https://www.lcsc.com/product-detail/C22548.html?s_z=n_q_C22548) | 0.14
 |  | 390k | 1 | C137735 (https://www.lcsc.com/product-detail/C137735.html?s_z=n_q_C137735) | 0.15
 |  | 2,2k | 2 | C4190 (https://www.lcsc.com/product-detail/C4190.html?s_z=n_q_C4190) | 0.14
 | Capacitor | 10n | 2 | C100042 (https://www.lcsc.com/product-detail/C100042.html?s_z=n_q_C100042) | 0.23
 |  | 100n | 26 | C14663 (https://www.lcsc.com/product-detail/C14663.html?s_z=n_q_C14663) | 0.56
 |  | 10u | 4 | C440198 (https://www.lcsc.com/product-detail/C440198.html?s_z=n_q_C440198) | 1.27
 |  | 1u | 1 | C28323 (https://www.lcsc.com/product-detail/C28323.html?s_z=n_q_C28323) | 0.24
 |  | 22u | 5 | C342620 (https://www.lcsc.com/product-detail/C342620.html?s_z=n_q_C342620) | 2.1
 |  | 4,7u | 2 | C98192 (https://www.lcsc.com/product-detail/C98192.html?s_z=n_q_C98192) | 0.18
 | VEML7700-TT | X | 1 | C1850416 (https://www.lcsc.com/product-detail/C1850416.html?s_z=n_q_C1850416) | 1.49
 | FS8205A | X | 1 | C2830320 (https://www.lcsc.com/product-detail/C2830320.html?s_z=n_q_C2830320) | 0.52
 | YLED0603B (led) | Blue | 1 | C19171394 (https://www.lcsc.com/product-detail/C19171394.html?s_z=n_q_C19171394) | 0.54
 | YLED0603G (led) | Green | 1 | C19273151 (https://www.lcsc.com/product-detail/C19273151.html?s_z=n_q_C19273151) | 0.54
 | KT-0603R (led) | Red | 1 | C2286 (https://www.lcsc.com/product-detail/C2286.html?s_z=n_q_C2286) | 0.59
 | MAX98357AETE+T | X | 1 | C910544 (https://www.lcsc.com/product-detail/C910544.html?s_z=n_q_C910544) | 1.24
 | MCP73871-2AAI/ML | X | 1 | C144351 (https://www.lcsc.com/product-detail/C144351.html?s_z=n_q_C144351) | 2.74
 | MT3608 | X | 2 | C84817 (https://www.lcsc.com/product-detail/C84817.html?s_z=n_q_C84817) | 0.69
 | SS14 (diode) | X | 2 | C2837270 (https://www.lcsc.com/product-detail/C2837270.html?s_z=n_q_C2837270) | 0.48
 | AHT20 | X | 1 | C2757850 (https://www.lcsc.com/product-detail/C2757850.html?s_z=n_q_C2757850) | 0.58
 | MCP23017T-E/ML | X | 1 | C629439 (https://www.lcsc.com/product-detail/C629439.html?s_z=n_q_C629439) | 1.46
 | micro sd card port | X | 1 | C506790 (https://www.lcsc.com/product-detail/C506790.html?s_z=n_q_C506790) | 3.66
 | USB-C port | X | 1 | C2765186 (https://www.lcsc.com/product-detail/C2765186.html?s_z=n_q_C2765186) | 1.17
 | DW01A | X | 1 | C351410 (https://www.lcsc.com/product-detail/C351410.html?s_z=n_q_C351410) | 0.75
 | Coil | 22u | 2 | C2826664 (https://www.lcsc.com/product-detail/C2826664.html?s_z=n_q_C2826664) | 0.64
 | AMS1117-3.3 | X | 1 | C6186 (https://www.lcsc.com/product-detail/C6186.html?s_z=n_q_C6186) | 0.99
 | AO3400A | X | 2 | C20917 (https://www.lcsc.com/product-detail/C20917.html?s_z=n_q_C20917) | 0.36
 | FFC / FPC connector 1mm | 8 pins | 4 | C262714 (https://www.lcsc.com/product-detail/C262714.html?s_z=n_q_C262714) | 0.99
 |  | 12 pins | 2 | C262718 (https://www.lcsc.com/product-detail/C262718.html?s_z=n_q_C262718) | 1.1
 | ESP32-S3-WROOM-1 | X | 1 | C2913202 (https://www.lcsc.com/product-detail/C2913202.html?s_z=n_q_C2913202) | 4.58
 |  |  |  |  | 30.94
Others components (not in LCSC) | Switch push buttons | 6mm.6mm.5.5mm | 17 | Link (https://fr.aliexpress.com/item/1005001629177989.html) | 1.22
 | EC11 rotary encoder | X | 1 | Link (https://fr.aliexpress.com/item/1005003824684681.html) | 1.33
 | Touch screen | 4 inch | 1 | Link (https://fr.aliexpress.com/item/1005005791515997.html) | 14.39
 | Speaker | 8 ohm | 1 | Link (https://fr.aliexpress.com/item/4000034945525.html) | 10.7
 | keyboard switch | X | 1 | Link (https://fr.aliexpress.com/item/1005006298192363.html?curPageLogUid=gooq9QGv7BWw) | 4.39
 | Servo motor | 180 degrees | 1 | Link (https://fr.aliexpress.com/item/1005006572297006.html?curPageLogUid=upkbVzHBRk64) | 2.7
 | LED COB | 24V 8W | 1 | Link (https://fr.aliexpress.com/item/1005006373977700.html) | 1.89
 | Heat sink | with fan 12V | 1 | Link (https://fr.aliexpress.com/item/1005003605697738.html) | 3.19
 | Male pins | 17 pins | 1 | Link (https://fr.aliexpress.com/item/4000873858801.html?mp=1) | 1.89
 | Female pins | 14 pins | 1
 | Battery | 18650 | 1 | Link (https://fr.aliexpress.com/item/1005008704468583.html?curPageLogUid=UXVh5AwultNA) | 6.59
 | Led strip | addressable 1m | 1 | Link (https://fr.aliexpress.com/item/1005009613294814.html?curPageLogUid=OopZgshG9YMS) | 4.99
 | 3D-printed insert | M3 | 12 | Link (https://fr.aliexpress.com/item/1005007653131713.html?curPageLogUid=Q60nQoBk4Yrg) | 1.69
 | Screw | M3 | 12 | Link (https://fr.aliexpress.com/item/32968616563.html?curPageLogUid=VC2mM7krZnQV) | 1.4
 | Micro SD card | 4go | 1 | Link (https://fr.aliexpress.com/item/1005008059516973.html?curPageLogUid=3sIpPzvfLVUV) | 3.29
 | FPC cable | 12pins 15cm 1mm | 1 | Link (https://fr.aliexpress.com/item/1005007561337665.html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) | 1.72
 |  | 8pins 10cm 1mm | 2 | Link (https://fr.aliexpress.com/item/1005007561337665.html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) | 2.18
 | epoxy resin | 50ml + 50ml | 1 | Link (https://fr.aliexpress.com/item/1005007345256355.html?curPageLogUid=9vanx70l8WJk) | 6.59
 | Water pump | 5V | 1 | Link (https://fr.aliexpress.com/item/1005006614378374.html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) | 1.69
 | Pipe | 1m | 1 | Link (https://fr.aliexpress.com/item/1005006614378374.html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) | 1.81
 |  |  |  |  | 73.65
PCB (JLCPCB) | Main PCB | X | 1 | Upload GERBER on JLCPCB | 1.7 | (I had a promo it's 3,4 instead)
 | Buttons PCB | X | 1 |  | 3.4
Décoration | Log (for the base) | 14-16cm | 2 | Link (https://fr.aliexpress.com/item/1005007635992230.html?mp=1) | 9.78
 | Temple | X | 1 | Link (https://fr.aliexpress.com/item/1005007500230985.html?curPageLogUid=3TB0Xy0rew2e) | 2.1
 | Moss 1 | 20g | 1 | Link (https://fr.aliexpress.com/item/1005005026348059.html?curPageLogUid=WHp4W42rZr0k) | 1.72
 | Moss 2 | 20g | 1 | Link (https://fr.aliexpress.com/item/1005005026348059.html?curPageLogUid=WHp4W42rZr0k) | 2.04
 | Cherry tree | X | 1 | Link (https://fr.aliexpress.com/item/1005003593401791.html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) | 3.89
 | PLA black + white | 1kg + 1kg | 1 | Link (https://www.amazon.fr/gp/product/B0CV4V5L7T/ref=ewc_pr_img_1?smid=AKWYTSYUMR87P&th=1) | 20.12
 | Bridge | X | 1 | Link (https://fr.aliexpress.com/item/1005003493992894.html?curPageLogUid=BrLVJl9Xb5AY) | 1.05
 |  |  |  |  | 40.7
Full price | 150.39
Real price | 94.51
Aliexpress | 38.35
LCSC | 30.94
Amazon | 20.12
JLCPCB | 5.1

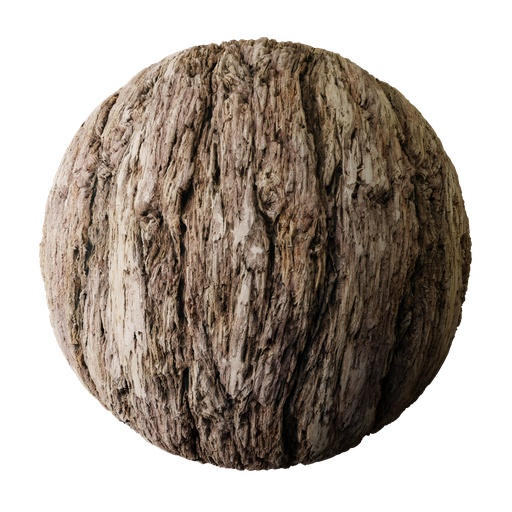
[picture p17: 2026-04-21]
blender/blender_projet/assets/materials/tree-bark_99e125b8-410a-4ab3-bea4-356172ee4fbe/preview.png

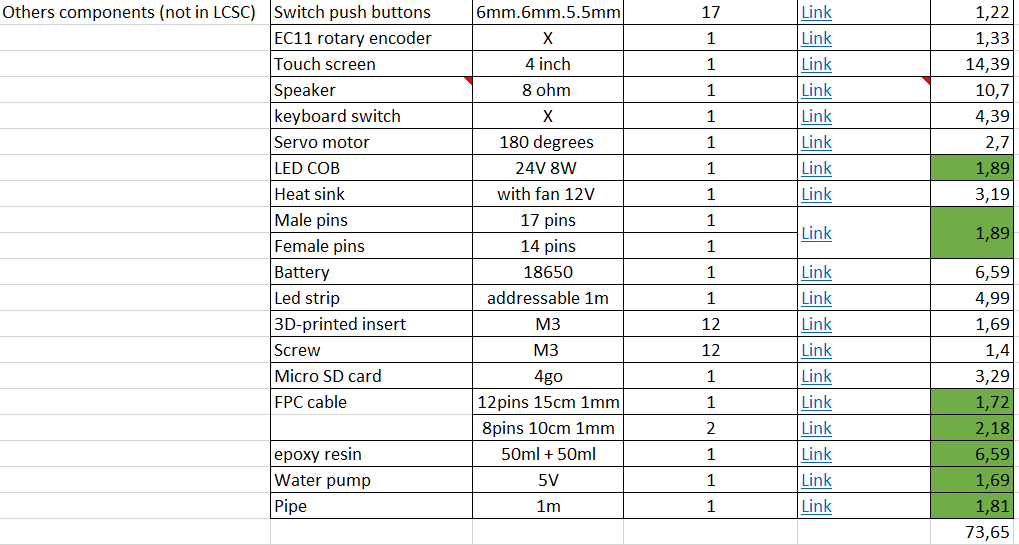
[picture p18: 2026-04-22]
Pictures/BOM2.png

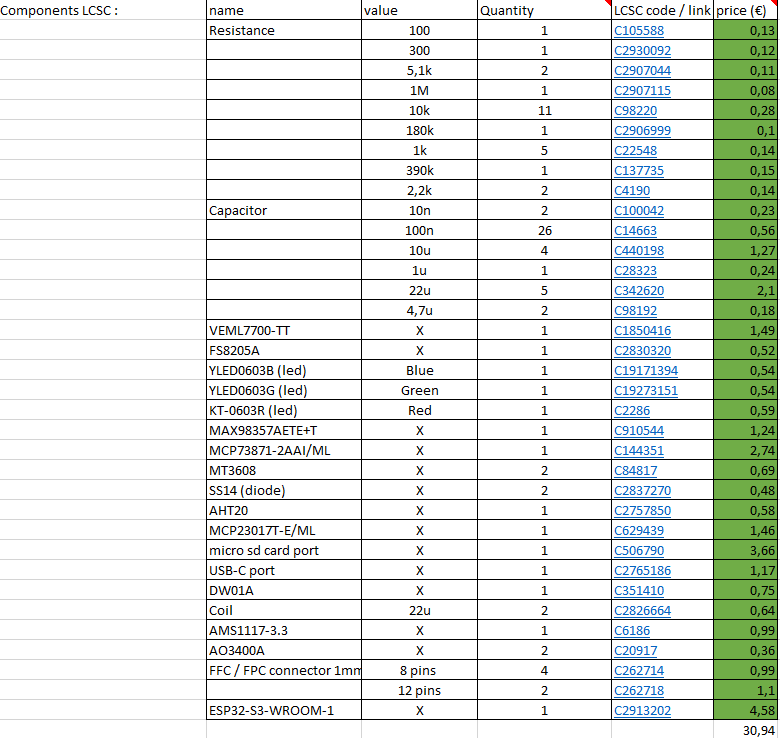
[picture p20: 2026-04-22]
Pictures/BOM1.png

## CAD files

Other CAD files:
CAD/Solidworks/Box_assembled.SLDASM
STEP_full_box_components.STEP
blender/Assemblage1 - dissipateur-2.STL
blender/Assemblage1 - supp_carte_sd-1.STL
blender/Assemblage1 - supp_switch-1.STL
blender/Assemblage1 - cache_lum-2.STL
blender/Assemblage1 - extension_btn_vfinal_UwU-1.STL
blender/Assemblage1 - supp_pcb_btn-1.STL
blender/Assemblage1 - supp_dissipateur-2.STL
blender/Assemblage1 - recup_riviere-1.STL
blender/Assemblage1 - uwuface-1.STL
blender/Assemblage1 - supp_usbc_port-1.STL
blender/Assemblage1 - supp_switch-2.STL
blender/Assemblage1 - screen-2.STL
blender/Assemblage1 - box_bottom-1.STL
blender/Assemblage1 - supp_potar-1.STL
blender/Assemblage1 - hp-1.STL
blender/Assemblage1 - back_box-1.STL
CAD/Solidworks/alarm_carte_sd_pcb.SLDPRT
CAD/Solidworks/back_box.SLDPRT
CAD/Solidworks/box_bottom.SLDPRT
CAD/Solidworks/box_top.SLDPRT
CAD/Solidworks/btn_extension2.SLDPRT
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

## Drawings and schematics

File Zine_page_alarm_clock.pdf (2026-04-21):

# Alarm Clock with dawn simulator

# Produced by Florian « Carabouille » CHARLES

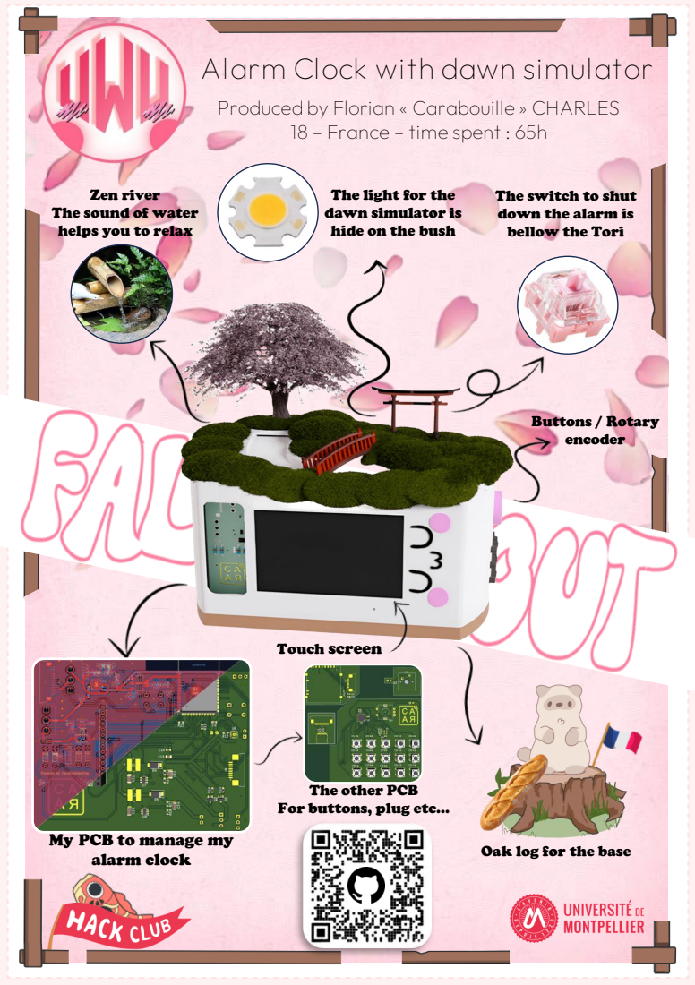
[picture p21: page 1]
alarm clock; Touch screen; Buttons / Rotary encoder

18 – France – time spent : 65h

Zen river
The sound of water
helps you to relax

The light for the
dawn simulator is
hide on the bush

The switch to shut
down the alarm is
bellow the Tori

The other PCB
For buttons, plug etc…

My PCB to manage my

Oak log for the base

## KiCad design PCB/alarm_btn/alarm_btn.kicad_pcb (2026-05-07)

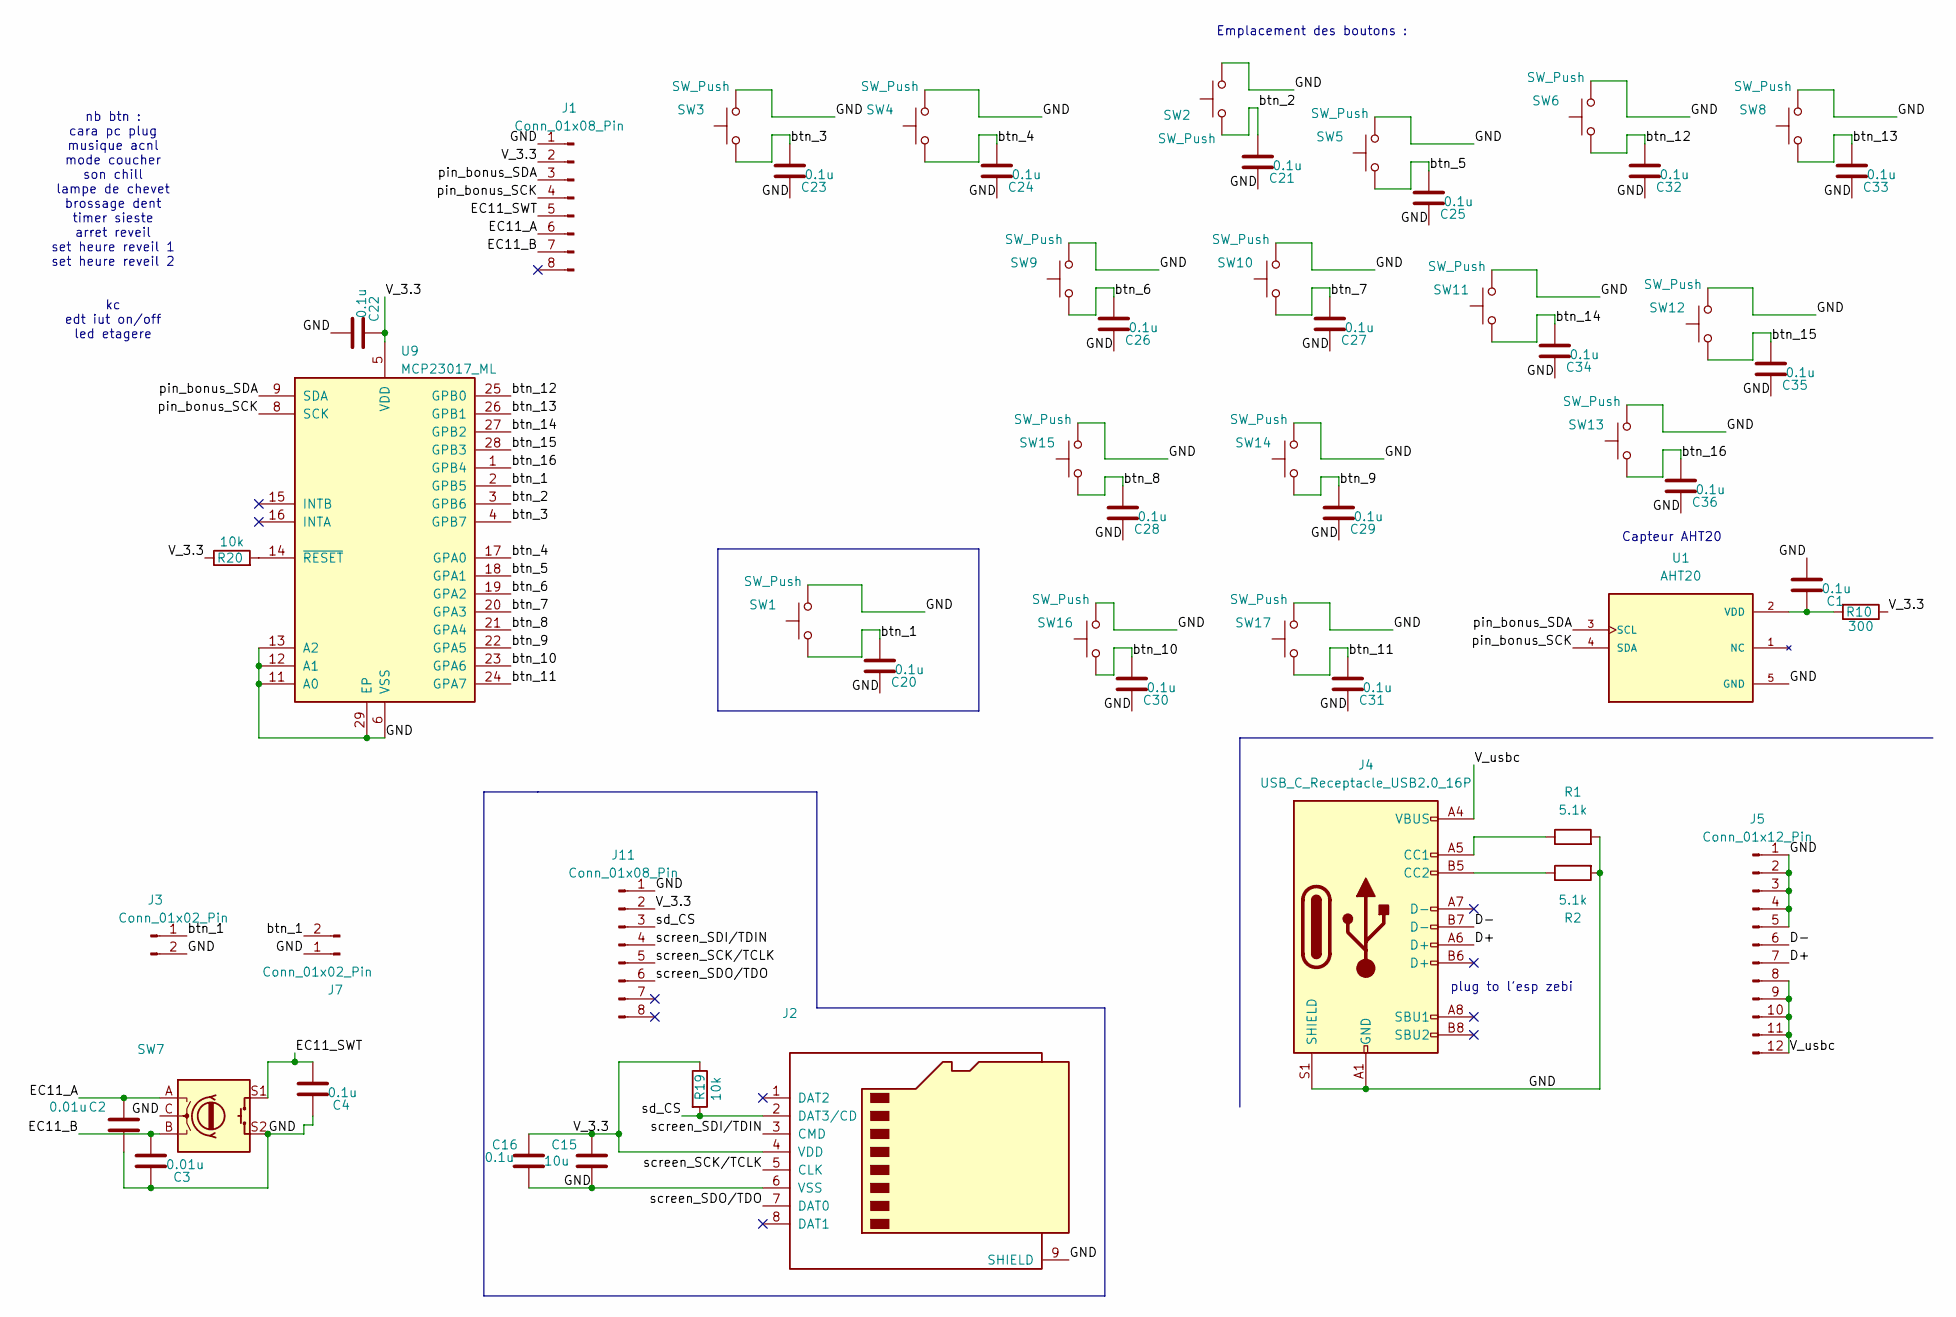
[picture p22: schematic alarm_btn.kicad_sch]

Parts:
C1, C4, C16, C20, C21, C22, C23, C24, C25, C26, C27, C28, C29, C30, C31, C32, C33, C34, C35, C36: 0.1u; C_0603_1608Metric; LCSC C14663
C2, C3: 0.01u; C_0603_1608Metric; LCSC C100042
C15: 10u; C_0805_2012Metric; LCSC C440198
J1, J11: Conn_01x08_Pin; JUSHUO_AFA07-S08FCA-00_1x8-1MP_P1.0mm_Horizontal; LCSC C262714
J2: Micro_SD_Card; SD_Hirose_DM1AA_SF_PEJ82; LCSC C506790
J3, J7: Conn_01x02_Pin; PinHeader_1x02_P2.54mm_Vertical
J4: USB_C_Receptacle_USB2.0_16P; USB_C_Receptacle_HRO_TYPE-C-31-M-12; LCSC C2765186
J5: Conn_01x12_Pin; JUSHUO_AFA07-S12FCA-00_1x12-1MP_P1.0mm_Horizontal; LCSC C262718
R1, R2: 5.1k; R_0603_1608Metric
R10: 300; R_0603_1608Metric; LCSC C2930092
R19, R20: 10k; R_0603_1608Metric; LCSC C98220
SW1: SW_Push; SW_Cherry_MX_1.00u_PCB
SW2, SW3, SW4, SW5, SW6, SW8, SW9, SW10, SW11, SW12, SW13, SW14, SW15, SW16, SW17: SW_Push; SW_PUSH_6mm
SW7: RotaryEncoder_Switch; RotaryEncoder_Alps_EC11E-Switch_Vertical_H20mm
U1: AHT20; PSON100P300X300X110-6N; PARTREV V1.0; LCSC C2757850
U9: MCP23017_ML; QFN-28-1EP_6x6mm_P0.65mm_EP4.25x4.25mm; LCSC C629439

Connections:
/D+: J4.A6 (D+), J5.7
/D-: J4.B7 (D-), J5.6
/EC11_A: C2.1, J1.6, SW7.A
/EC11_B: C3.1, J1.7, SW7.B
/EC11_SWT: C4.2, J1.5, SW7.S1
/GND: C1.2, C2.2, C3.2, C4.1, C15.1, C16.2, C20.1, C21.1, C22.2, C23.1, C24.1, C25.1, C26.1, C27.1, C28.1, C29.1, C30.1, C31.1, C32.1, C33.1, C34.1, C35.1, C36.1, J1.1, J2.6 (VSS), J2.9 (SHIELD), J3.2, J4.A1 (GND), J4.A12 (GND), J4.B1 (GND), J4.B12 (GND), J4.S1 (SHIELD), J5.1, J5.2, J5.3, J5.4, J5.5, J7.1, J11.1, R1.2, R2.2, SW1.2, SW2.1, SW3.2, SW4.2, SW5.2, SW6.2, SW7.C, SW7.S2, SW8.2, SW9.2, SW10.2, SW11.2, SW12.2, SW13.2, SW14.2, SW15.2, SW16.2, SW17.2, U1.5 (GND), U9.6 (VSS), U9.11 (A0), U9.12 (A1), U9.13 (A2), U9.29 (EP)
/V_3.3: C15.2, C16.1, C22.1, J1.2, J2.4 (VDD), J11.2, R10.1, R19.1, R20.1, U9.5 (VDD)
/V_usbc: J4.A4 (VBUS), J4.A9 (VBUS), J4.B4 (VBUS), J4.B9 (VBUS), J5.8, J5.9, J5.10, J5.11, J5.12
/btn_1: C20.2, J3.1, J7.2, SW1.1, U9.2 (GPB5)
/btn_2: C21.2, SW2.2, U9.3 (GPB6)
/btn_3: C23.2, SW3.1, U9.4 (GPB7)
/btn_4: C24.2, SW4.1, U9.17 (GPA0)
/btn_5: C25.2, SW5.1, U9.18 (GPA1)
/btn_6: C26.2, SW9.1, U9.19 (GPA2)
/btn_7: C27.2, SW10.1, U9.20 (GPA3)
/btn_8: C28.2, SW15.1, U9.21 (GPA4)
/btn_9: C29.2, SW14.1, U9.22 (GPA5)
/btn_10: C30.2, SW16.1, U9.23 (GPA6)
/btn_11: C31.2, SW17.1, U9.24 (GPA7)
/btn_12: C32.2, SW6.1, U9.25 (GPB0)
/btn_13: C33.2, SW8.1, U9.26 (GPB1)
/btn_14: C34.2, SW11.1, U9.27 (GPB2)
/btn_15: C35.2, SW12.1, U9.28 (GPB3)
/btn_16: C36.2, SW13.1, U9.1 (GPB4)
/pin_bonus_SCK: J1.4, U1.4 (SDA), U9.8 (SCK)
/pin_bonus_SDA: J1.3, U1.3 (SCL), U9.9 (SDA)
/screen_SCK/TCLK: J2.5 (CLK), J11.5
/screen_SDI/TDIN: J2.3 (CMD), J11.4
/screen_SDO/TDO: J2.7 (DAT0), J11.6
/sd_CS: J2.2 (DAT3/CD), J11.3, R19.2
unnamed: J4.A5 (CC1), R1.1
unnamed: J4.B5 (CC2), R2.1
unnamed: C1.1, R10.2, U1.2 (VDD)
unnamed: R20.2, U9.14 (~RESET)

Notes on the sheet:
Capteur AHT20
Emplacement des boutons :
nb btn : cara pc plug musique acnl mode coucher son chill lampe de chevet brossage dent timer sieste arret reveil set heure reveil 1 set heure reveil 2 kc edt iut on/off led etagere
plug to l'esp zebi

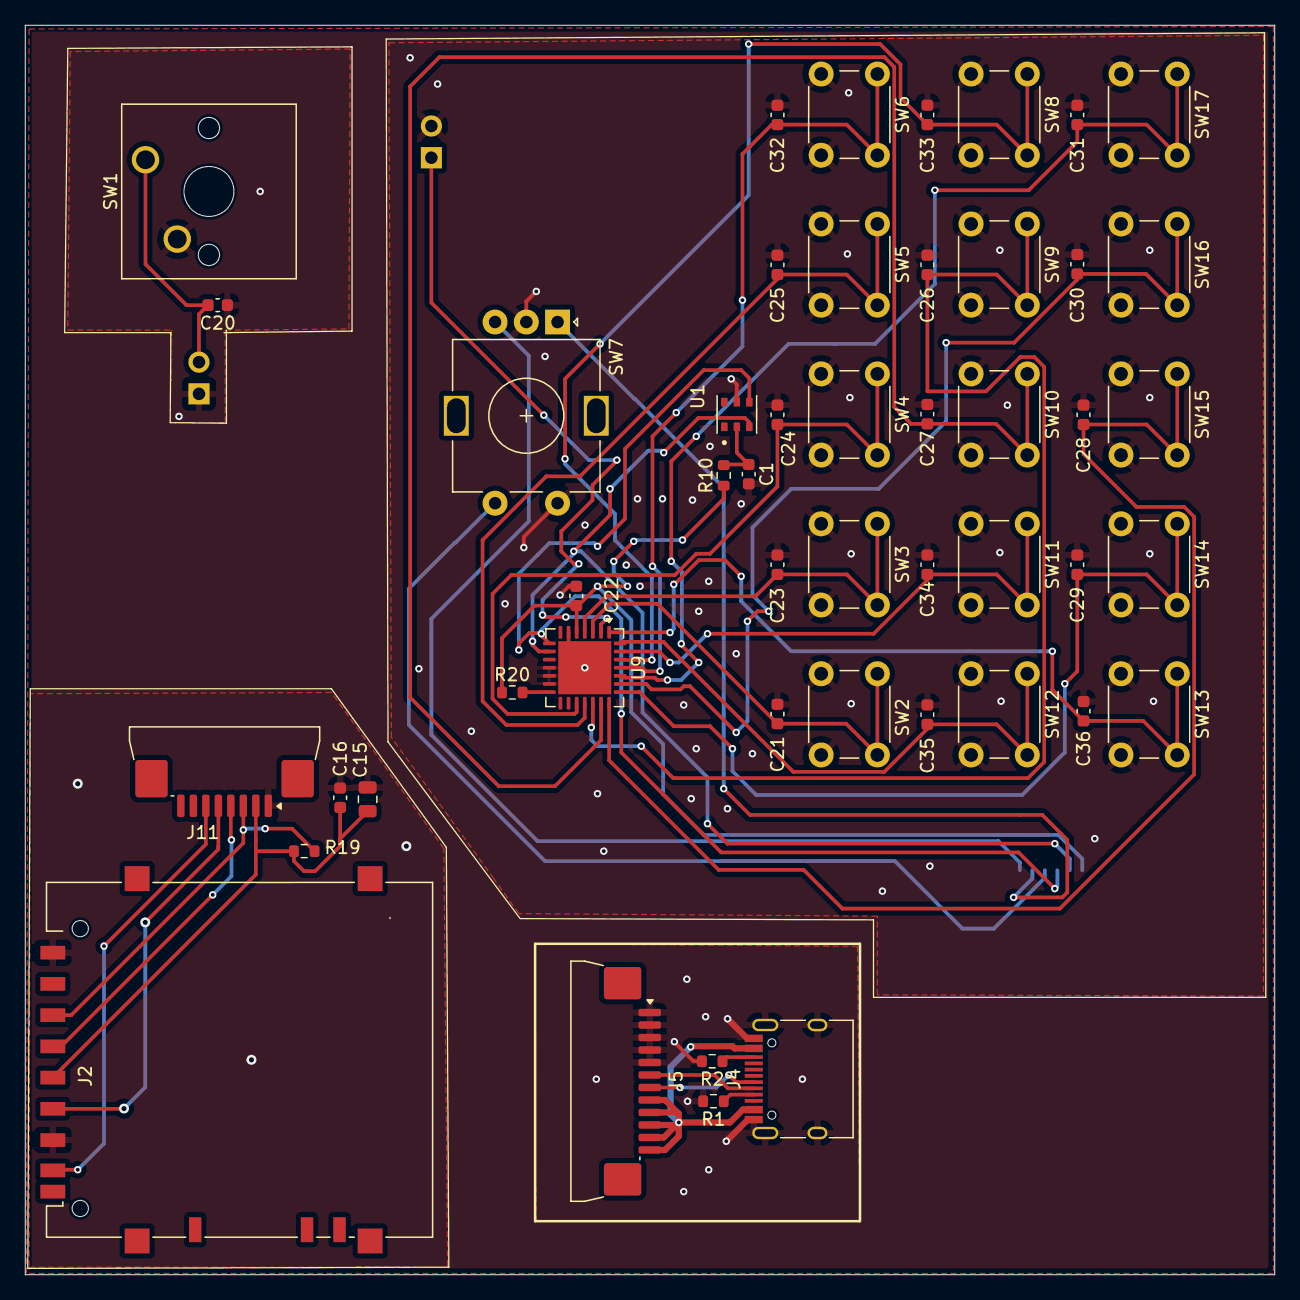
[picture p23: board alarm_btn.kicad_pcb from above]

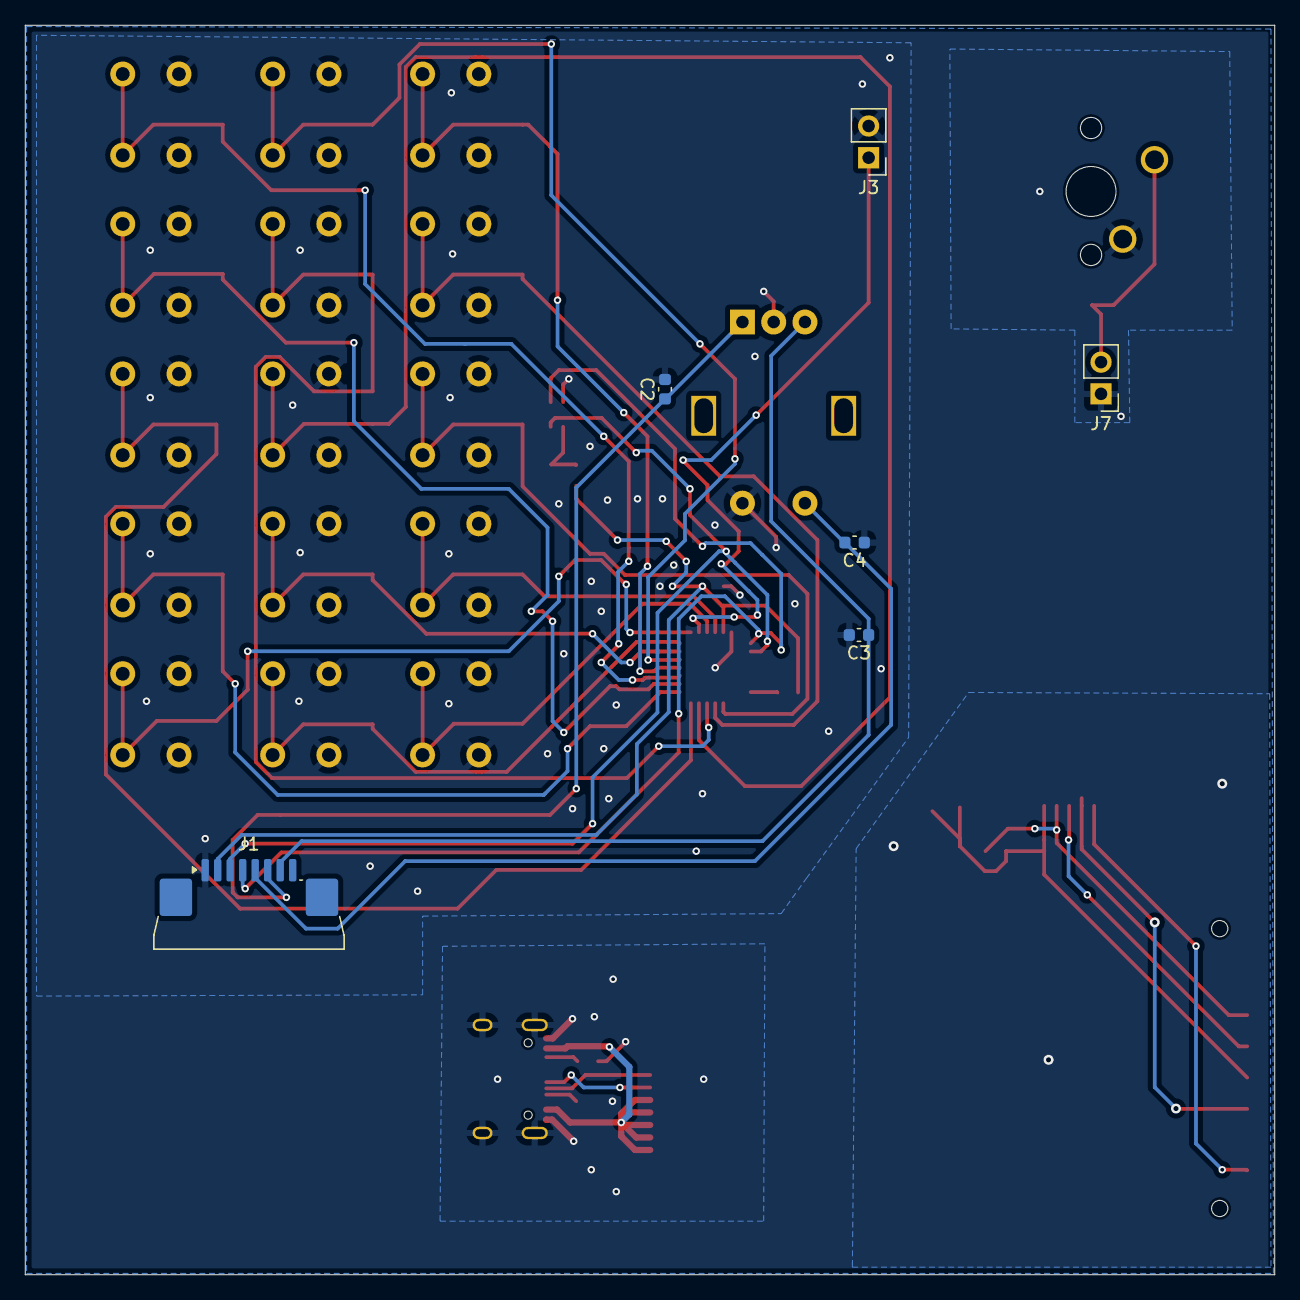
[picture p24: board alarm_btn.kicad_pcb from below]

Board: 2 copper layers, 100.0 x 100.0 mm, 54 parts (6 on the bottom side), 34 nets.

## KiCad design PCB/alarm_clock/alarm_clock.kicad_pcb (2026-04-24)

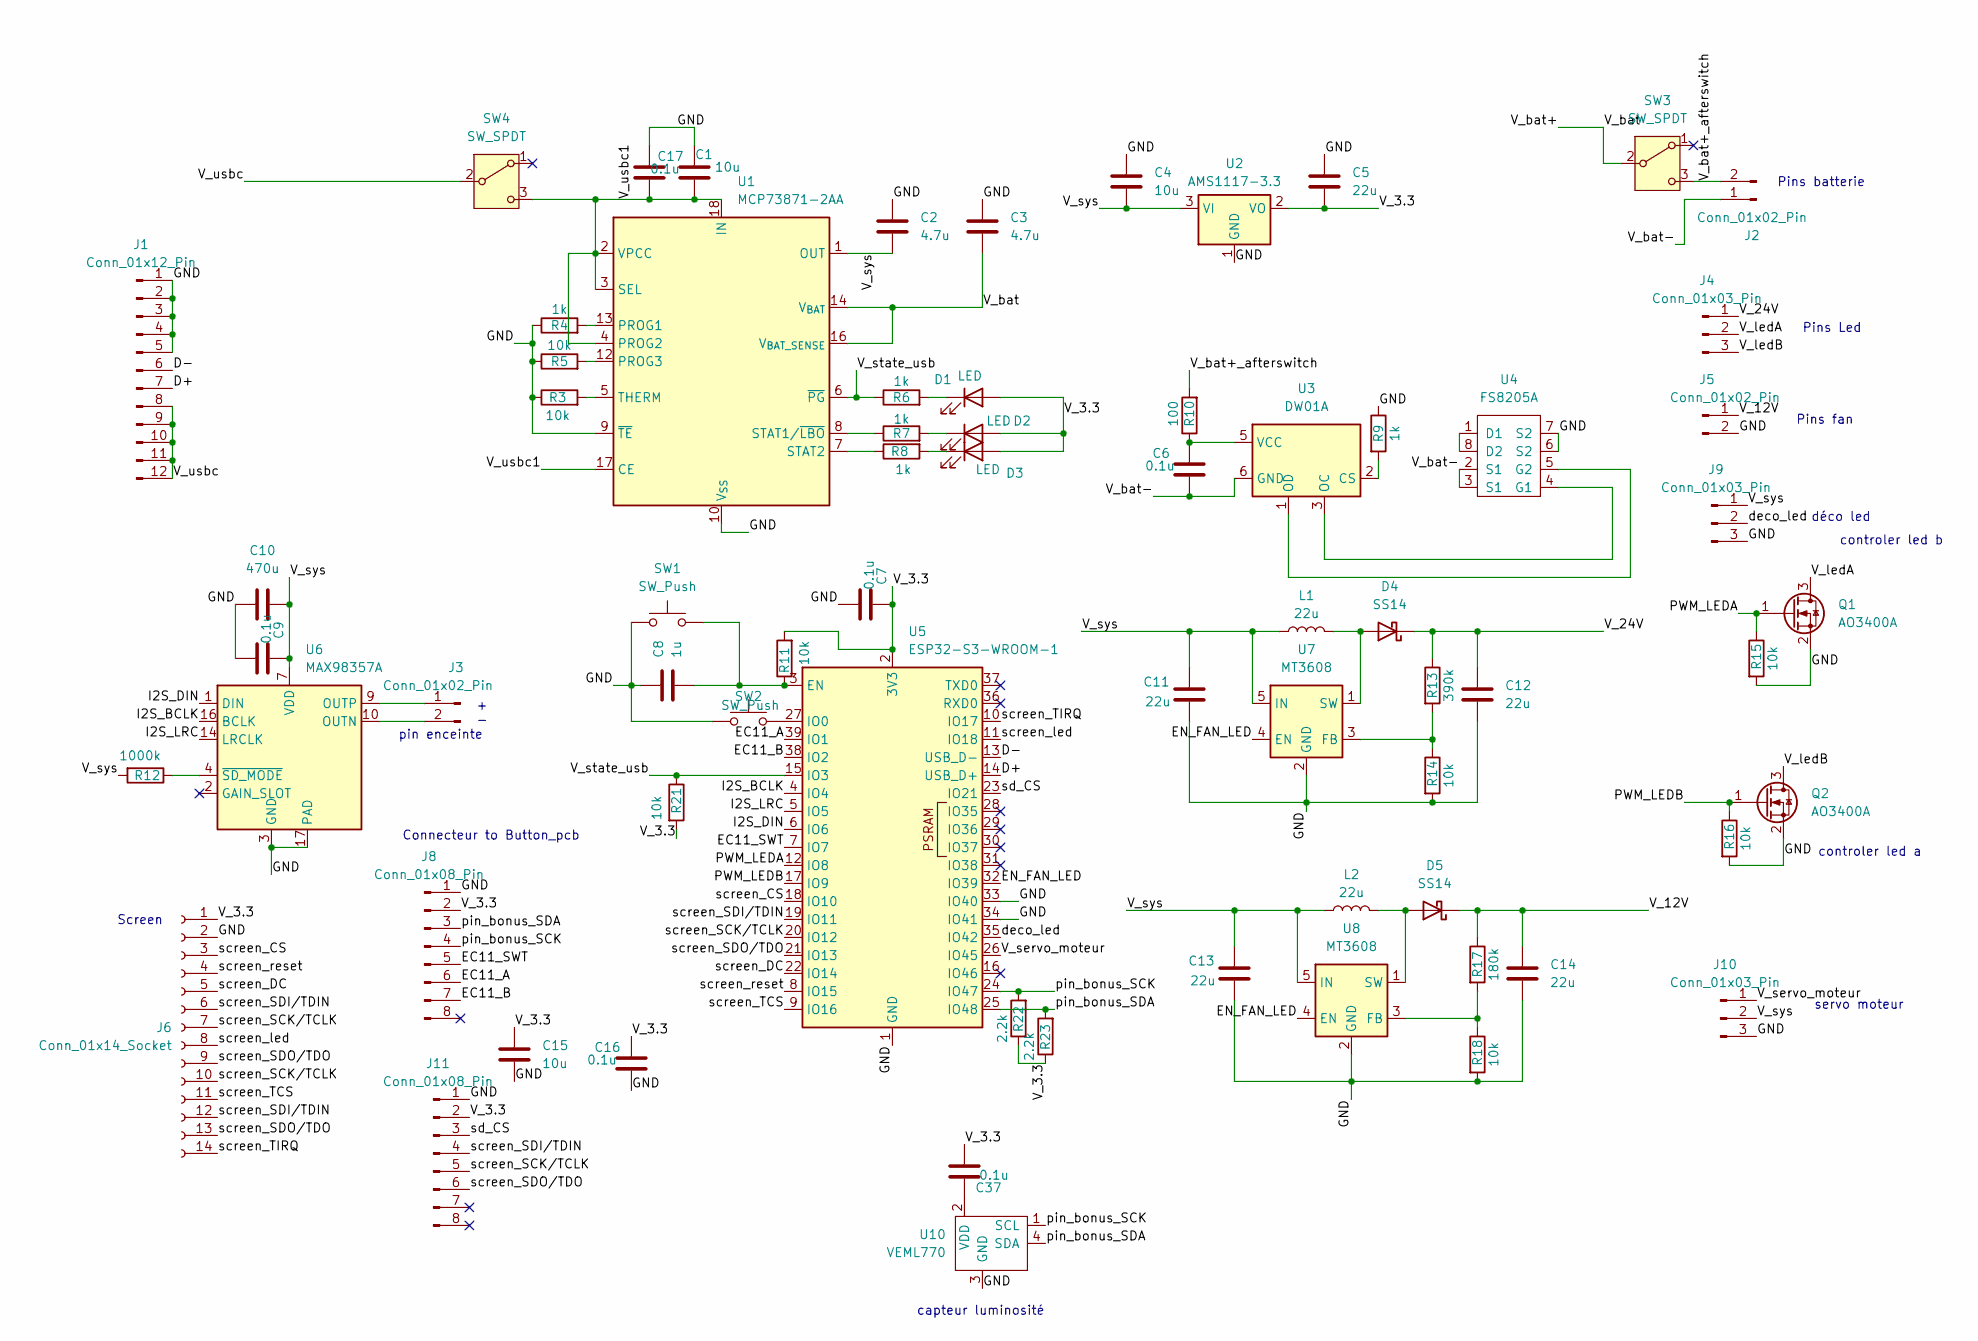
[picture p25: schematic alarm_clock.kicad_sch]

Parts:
C1, C4, C15: 10u; C_0805_2012Metric; LCSC C440198
C2, C3: 4.7u; C_0805_2012Metric; LCSC C98192
C5: 22u; C_0805_2012Metric; LCSC C342620
C6, C7, C9, C16, C17, C37: 0.1u; C_0603_1608Metric; LCSC C14663
C8: 1u; C_0805_2012Metric; LCSC C28323
C10: 470u; CP_Radial_D6.3mm_P2.50mm
C11, C12, C13, C14: 22u; C_1206_3216Metric; LCSC C342620
D1: LED; LED_0603_1608Metric; LCSC C19171394
D2: LED; LED_0603_1608Metric; LCSC C2286
D3: LED; LED_0603_1608Metric; LCSC C19273151
D4, D5: SS14; D_SMA; LCSC C2837270
J1: Conn_01x12_Pin; JUSHUO_AFA07-S12FCA-00_1x12-1MP_P1.0mm_Horizontal; LCSC C262718
J2, J3, J5: Conn_01x02_Pin; PinHeader_1x02_P2.54mm_Vertical
J4, J9, J10: Conn_01x03_Pin; PinHeader_1x03_P2.54mm_Vertical
J6: Conn_01x14_Socket; PinSocket_1x14_P2.54mm_Vertical
J8, J11: Conn_01x08_Pin; JUSHUO_AFA07-S08FCA-00_1x8-1MP_P1.0mm_Horizontal; LCSC C262714
L1, L2: 22u; IND_CD54_SUM; LCSC C2826664
Q1, Q2: AO3400A; SOT-23; LCSC C20917
R3, R5, R11, R14, R15, R16, R18, R21: 10k; R_0603_1608Metric; LCSC C98220
R4, R6, R7, R8, R9: 1k; R_0603_1608Metric; LCSC C22548
R10: 100; R_0603_1608Metric; LCSC C105588
R12: 1000k; R_0603_1608Metric; LCSC C2907115
R13: 390k; R_0603_1608Metric; LCSC C137735
R17: 180k; R_0603_1608Metric; LCSC C2906999
R22, R23: 2.2k; R_0603_1608Metric; LCSC C4190
SW1, SW2: SW_Push; SW_PUSH_6mm
SW3, SW4: SW_SPDT; switch_on_on
U1: MCP73871-2AA; QFN-20-1EP_4x4mm_P0.5mm_EP2.5x2.5mm; LCSC C144351
U2: AMS1117-3.3; SOT-223-3_TabPin2; LCSC C6186
U3: DW01A; SOT-23-6; LCSC C351410
U4: FS8205A; TSSOP-8_4.4x3mm_P0.65mm; LCSC C2830320
U5: ESP32-S3-WROOM-1; LCSC C2913202
U6: MAX98357A; TQFN-16-1EP_3x3mm_P0.5mm_EP1.23x1.23mm; LCSC C910544
U7, U8: MT3608; SOT-23-6; LCSC C84817
U10: VEML770; XDCR_VEML7700-TR; LCSC C1850416

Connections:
/D+: J1.7, U5.14 (USB_D+)
/D-: J1.6, U5.13 (USB_D-)
/EC11_A: J8.6, U5.39 (IO1)
/EC11_B: J8.7, U5.38 (IO2)
/EC11_SWT: J8.5, U5.7 (IO7)
/EN_FAN_LED: U5.32 (IO39), U7.4 (EN), U8.4 (EN)
/GND: C1.1, C2.2, C3.2, C4.1, C5.1, C7.2, C8.2, C9.2, C10.1, C11.2, C12.2, C13.2, C14.2, C15.2, C16.2, C17.1, J1.1, J1.2, J1.3, J1.4, J1.5, J5.2, J6.2, J8.1, J9.3, J10.3, J11.1, Q1.2 (S), Q2.2 (S), R3.1, R4.1, R5.1, R9.1, R14.2, R15.2, R16.2, R18.2, SW1.1, SW2.1, U1.9 (~TE), U1.10 (V_{SS}), U1.11 (V_{SS}), U1.21 (V_{SS}), U2.1 (GND), U4.6 (S2), U4.7 (S2), U5.1 (GND), U5.33 (IO40), U5.34 (IO41), U5.40 (GND), U5.41 (GND), U6.3 (GND), U6.11 (GND), U6.15 (GND), U6.17 (PAD), U7.2 (GND), U8.2 (GND), U10.3 (GND); also elsewhere on the board
/I2S_BCLK: U5.4 (IO4), U6.16 (BCLK)
/I2S_DIN: U5.6 (IO6), U6.1 (DIN)
/I2S_LRC: U5.5 (IO5), U6.14 (LRCLK)
/PWM_LEDA: Q1.1 (G), R15.1, U5.12 (IO8)
/PWM_LEDB: Q2.1 (G), R16.1, U5.17 (IO9)
/V_3.3: C5.2, C7.1, C15.1, C16.1, C37.2, D1.2 (A), D2.2 (A), D3.2 (A), J6.1, J8.2, J11.2, R11.2, R21.2, R22.1, R23.1, U2.2 (VO), U5.2 (3V3); also elsewhere on the board
/V_12V: C14.1, D5.1 (K), J5.1, R17.1
/V_24V: C12.1, D4.1 (K), J4.1, R13.1
/V_bat: C3.1, SW3.2 (B), U1.14 (V_{BAT}), U1.15 (V_{BAT}), U1.16 (V_{BAT_SENSE})
/V_bat+_afterswitch: J2.2, R10.2, SW3.3 (C)
/V_bat-: C6.2, J2.1, U3.6 (GND), U4.2 (S1), U4.3 (S1)
/V_ledA: J4.2, Q1.3 (D)
/V_ledB: J4.3, Q2.3 (D)
/V_servo_moteur: J10.1, U5.26 (IO45)
/V_state_usb: R6.1, R21.1, U1.6 (~PG), U5.15 (IO3)
/V_sys: C2.1, C4.2, C9.1, C10.2, C11.1, C13.1, J9.1, J10.2, L1.1, L2.1, R12.2, U1.1 (OUT), U1.20 (OUT), U2.3 (VI), U6.7 (VDD), U6.8 (VDD), U7.5 (IN), U8.5 (IN)
/V_usbc: J1.8, J1.9, J1.10, J1.11, J1.12, SW4.2 (B)
/V_usbc1: C1.2, C17.2, SW4.3 (C), U1.2 (VPCC), U1.3 (SEL), U1.4 (PROG2), U1.17 (CE), U1.18 (IN), U1.19 (IN)
/deco_led: J9.2, U5.35 (IO42)
/pin_bonus_SCK: J8.4, R22.2, U5.24 (IO47), U10.1 (SCL)
/pin_bonus_SDA: J8.3, R23.2, U5.25 (IO48), U10.4 (SDA)
/screen_CS: J6.3, U5.18 (IO10)
/screen_DC: J6.5, U5.22 (IO14)
/screen_SCK/TCLK: J6.7, J6.10, J11.5, U5.20 (IO12)
/screen_SDI/TDIN: J6.6, J6.12, J11.4, U5.19 (IO11)
/screen_SDO/TDO: J6.9, J6.13, J11.6, U5.21 (IO13)
/screen_TCS: J6.11, U5.9 (IO16)
/screen_TIRQ: J6.14, U5.10 (IO17)
/screen_led: J6.8, U5.11 (IO18)
/screen_reset: J6.4, U5.8 (IO15)
/sd_CS: J11.3, U5.23 (IO21); also elsewhere on the board
unnamed: D1.1 (K), R6.2
unnamed: D2.1 (K), R7.2
unnamed: D3.1 (K), R8.2
unnamed: D4.2 (A), L1.2, U7.1 (SW)
unnamed: D5.2 (A), L2.2, U8.1 (SW)
unnamed: J3.1, U6.9 (OUTP)
unnamed: J3.2, U6.10 (OUTN)
unnamed: R4.2, U1.13 (PROG1)
unnamed: R5.2, U1.12 (PROG3)
unnamed: R7.1, U1.8 (STAT1/~LBO)
unnamed: R8.1, U1.7 (STAT2)
unnamed: R3.2, U1.5 (THERM)
unnamed: R9.2, U3.2 (CS)
unnamed: U3.3 (OC), U4.4 (G1)
unnamed: U3.1 (OD), U4.5 (G2)
unnamed: C6.1, R10.1, U3.5 (VCC)
unnamed: U4.1 (D1), U4.8 (D2)
unnamed: C8.1, R11.1, SW1.2, U5.3 (EN)
unnamed: SW2.2, U5.27 (IO0)
unnamed: R12.1, U6.4 (~SD_MODE)
unnamed: R13.2, R14.1, U7.3 (FB)
unnamed: R17.2, R18.1, U8.3 (FB)
unnamed: C37.1, U10.2 (VDD)

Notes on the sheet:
controler led b
Pins fan
pin enceinte
+ -
Pins Led
controler led a
servo moteur
Pins batterie
capteur luminosité
Screen
déco led
Connecteur to Button_pcb

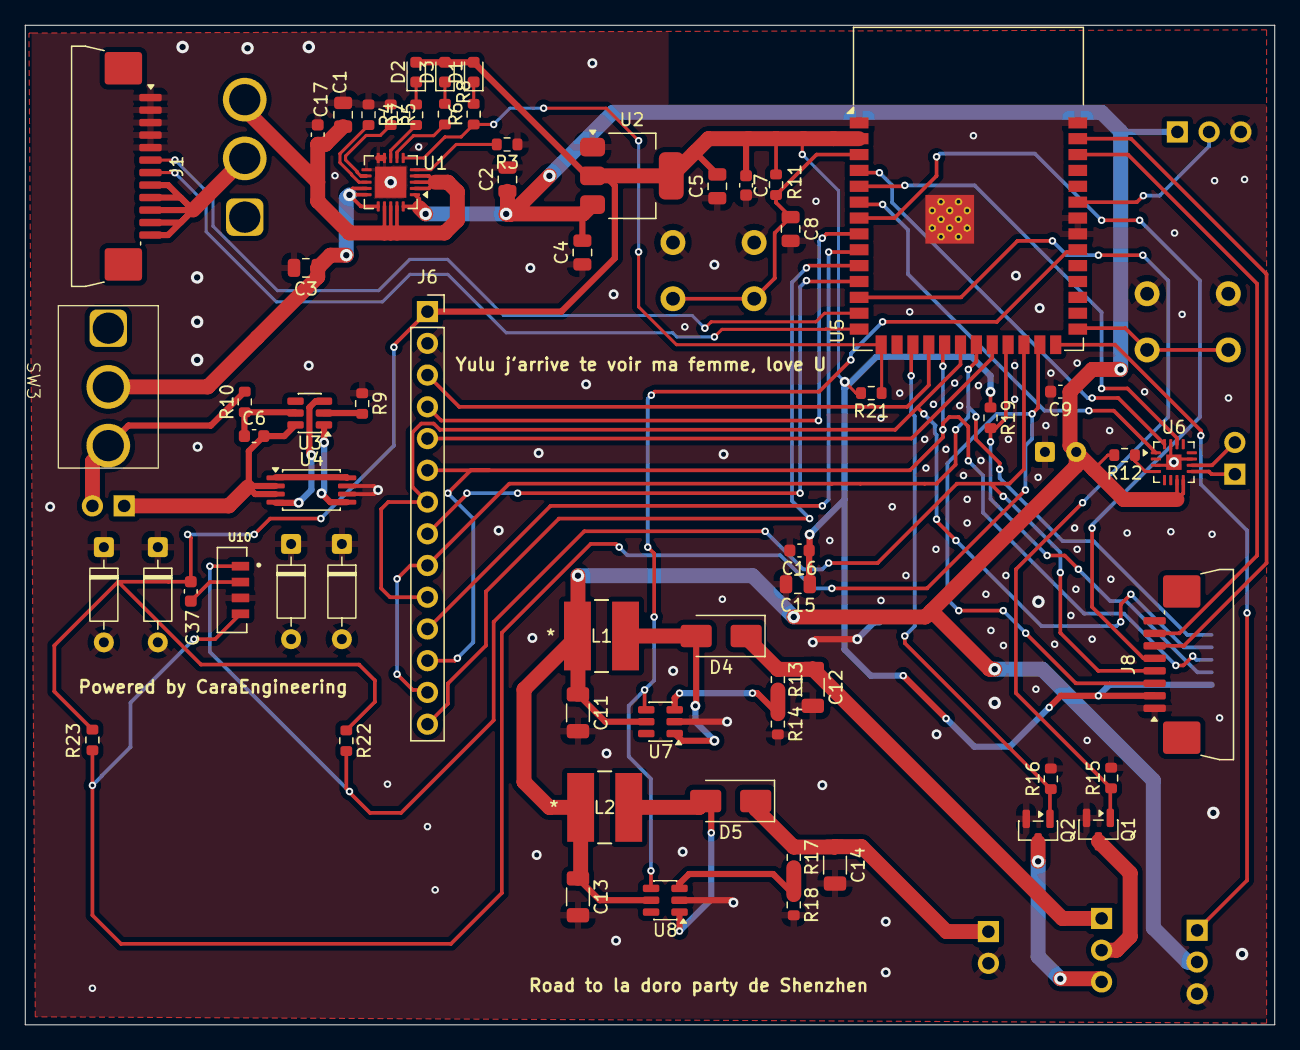
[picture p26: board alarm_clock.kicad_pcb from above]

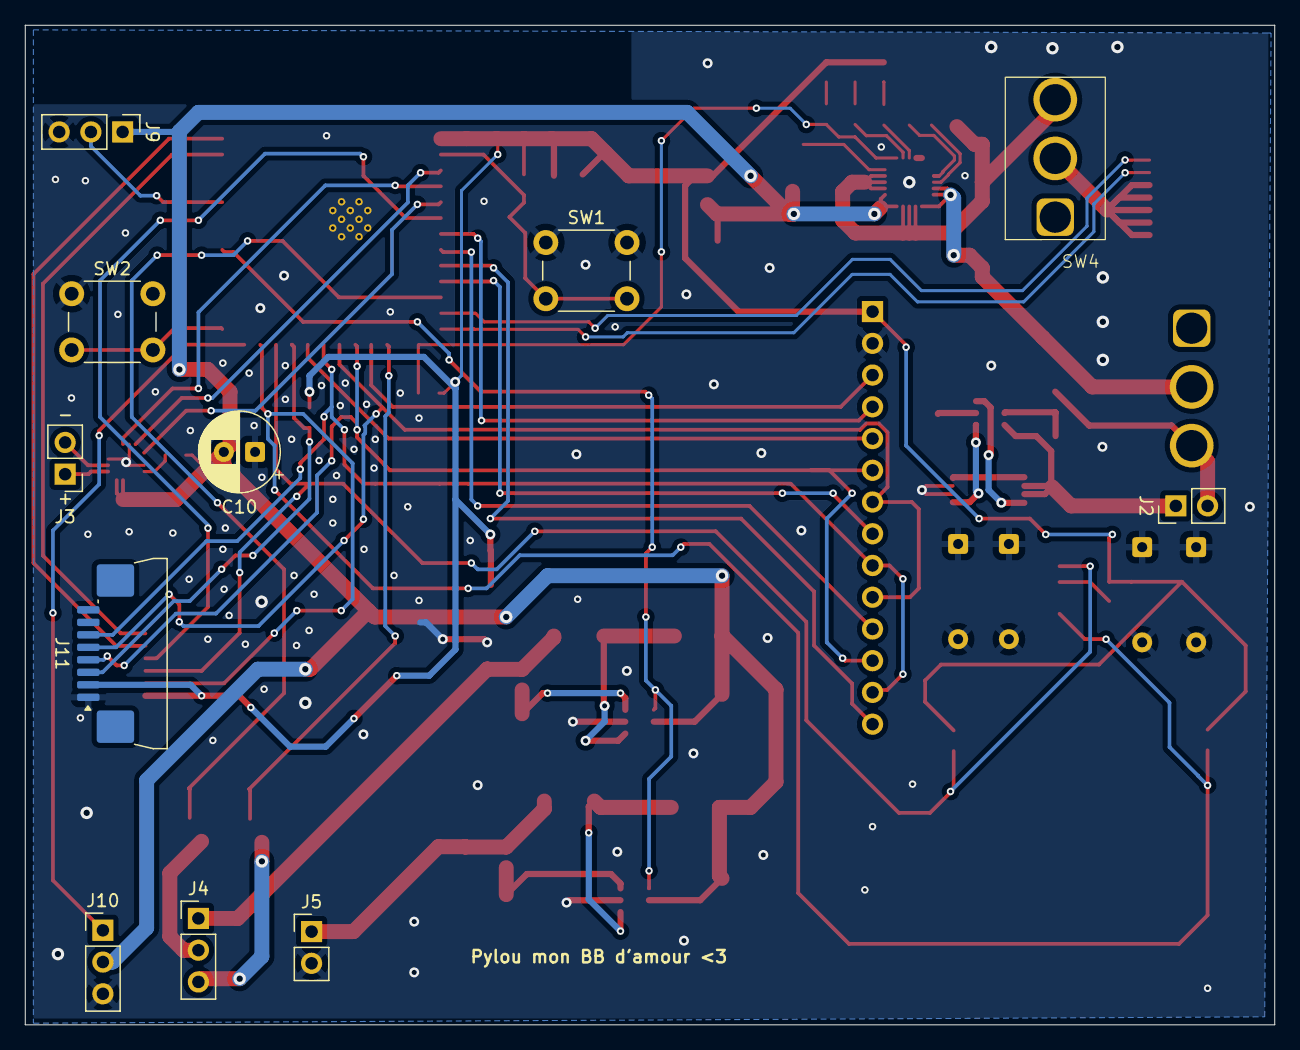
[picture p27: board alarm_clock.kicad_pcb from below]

Board: 2 copper layers, 100.0 x 80.0 mm, 74 parts (11 on the bottom side), 61 nets.

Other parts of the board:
D15, D15#2, D15#3, D15#4: 1N4148; D_DO-35_SOD27_P7.62mm_Horizontal
R19: 10k; R_0603_1608Metric

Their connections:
/GND: D15.1 (K), D15.2 (A), D15#2.1 (K), D15#2.2 (A), D15#3.1 (K), D15#3.2 (A), D15#4.1 (K), D15#4.2 (A); also elsewhere on the board
/V_3.3: R19.1; also elsewhere on the board
/sd_CS: R19.2; also elsewhere on the board

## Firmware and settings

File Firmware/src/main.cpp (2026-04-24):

#include <Arduino.h>
#include <time.h>
#include <WiFi.h>
#include "Adafruit_VEML7700.h"
#include <Adafruit_AHTX0.h>
#include <ESP32Servo.h>
#include <Adafruit_MCP23X17.h>
#include "stdio.h"
#include <ESP_Knob.h>
#include <Wire.h>
#include <SD.h>
#include <SPI.h>
#include <Audio.h>
#include <TFT_eSPI.h>



// <>
//I2C
#define I2C_SDA 25
#define I2C_SCL 24
TwoWire I2C = TwoWire(0);


//GESTION AUDIO
#define SD_CS_PIN 23

#define I2S_BCLK_PIN 4
#define I2S_LRC_PIN  5 
#define I2S_DOUT_PIN 6
Audio audio;

// Ecran / heure 

TFT_eSPI tft = TFT_eSPI(); 

// wifi logs 
const char* ssid     = "PlanetCampus - Prive 004302";
const char* password = "SAWDUASqCFnoT"; //that's my real password I've no enemies :)


const char* ntpServer = "fr.pool.ntp.org";
const long  gmtOffset_sec = 3600;      // GMT +1
const int   daylightOffset_sec = 3600; // heure été

void ShowHour() {
  struct tm timeinfo;
  if(!getLocalTime(&timeinfo)){
    Serial.println("Erreur de récupération de l'heure");
    return;
  }
  tft.setTextColor(TFT_GREEN, TFT_BLACK); // Vert sur fond Noir
  
  // 7segements police
  tft.setTextFont(7); 
  tft.setTextSize(1.5); 

  // Position x y
  tft.setCursor(50, 100);

  // show with the format hours : minutes : secondes
  tft.printf("%02d:%02d:%02d", timeinfo.tm_hour, timeinfo.tm_min, timeinfo.tm_sec);
  
  // show date
  tft.setTextFont(4);
  tft.setTextColor(TFT_WHITE, TFT_BLACK);
  tft.setCursor(100, 160);
  tft.printf("%02d/%02d/%02d", timeinfo.tm_mday, timeinfo.tm_mon + 1, timeinfo.tm_year + 1900);
}


//VEML7700
Adafruit_VEML7700 veml = Adafruit_VEML7700();

//AHT20
Adafruit_AHTX0 aht;

// PIN BONUS
#define BUTTON1_PIN 1 //btn16
#define BUTTON2_PIN 2 //btn1
#define BUTTON3_PIN 3 //btn2
#define BUTTON4_PIN 4 //btn3
#define BUTTON5_PIN 5 //btn...
#define BUTTON6_PIN 6
#define BUTTON7_PIN 7
#define BUTTON8_PIN 8
#define BUTTON9_PIN 9
#define BUTTON10_PIN 10
#define BUTTON11_PIN 11
#define BUTTON12_PIN 12
#define BUTTON13_PIN 13
#define BUTTON14_PIN 14
#define BUTTON15_PIN 15
#define BUTTON16_PIN 16
Adafruit_MCP23X17 mcp;

#define PIN_SG90 45
Servo sg90;

//pin PWM LED 
const int LEDA = 12;
const int LEDB = 17;


// pin Enable MT3608 led / fan
const int EN_mt3608 = 32;


// EC11
#define GPIO_KNOB_A 39
#define GPIO_KNOB_B 38
const int swt_ec11 = 7;
ESP_Knob *knob;

void onKnobLeftEventCallback(int count, void *usr_data)
{
    Serial.printf("Detect left event, count is %d\n", count);
}

void onKnobRightEventCallback(int count, void *usr_data)
{
    Serial.printf("Detect right event, count is %d\n", count);
}

void onKnobHighLimitEventCallback(int count, void *usr_data)
{
    Serial.printf("Detect high limit event, count is %d\n", count);
}

void onKnobLowLimitEventCallback(int count, void *usr_data)
{
    Serial.printf("Detect low limit event, count is %d\n", count);
}

void onKnobZeroEventCallback(int count, void *usr_data)
{
    Serial.printf("Detect zero event, count is %d\n", count);
}




void setup() {


  //screen
  tft.init();
  tft.setRotation(1);
  tft.fillScreen(TFT_BLACK);

  // wait the wifi connection
  tft.setTextFont(4);
  tft.setTextColor(TFT_WHITE, TFT_BLACK);
  tft.setCursor(10, 10);
  tft.println("Connexion WiFi...");

  // wifi
  WiFi.begin(ssid, password);
  while (WiFi.status() != WL_CONNECTED) {
    delay(500);
    Serial.print(".");
  }
  
  tft.println("WiFi OK !");
  tft.println("Recuperation heure...");

  // Init hour
  configTime(gmtOffset_sec, daylightOffset_sec, ntpServer);
  
  tft.fillScreen(TFT_BLACK);




  //I2C
  I2C.begin(I2C_SDA, I2C_SCL, 100000);


  // AUDIO / CARTE SD 
 Serial.println("\n--- Test Audio : ESP32-audioI2S ---");

  // 1. Initialisation de la carte SD
  if (!SD.begin(SD_CS_PIN)) {
    Serial.println("ERREUR : SD introuvable !");
    while(1); 
  }
  Serial.println("SD OK !");
  
  audio.setPinout(I2S_BCLK_PIN, I2S_LRC_PIN, I2S_DOUT_PIN);
  
  // volume de 0 à 21
  audio.setVolume(5); 

  // ici on doit le mouv si on veut pas que la musique se lance au démarrage 

  bool succes = audio.connecttoFS(SD, "/test.mp3"); // change here the name of the song "test"
  
  if(succes) {
    Serial.println("Lecture en cours...");
  } else {
    Serial.println("Impossible de lire le fichier !");
  }



  // VEML7700
  Serial.begin(115200);
  while (!Serial) { delay(10); }
  Serial.println("Adafruit VEML7700 Auto Lux Test");

  if (!veml.begin()) {
    Serial.println("Sensor not found");
    while (1);
  }
  Serial.println("Sensor found");

  // AHT20
  Serial.println("Adafruit AHT10/AHT20 demo!");

  if (!aht.begin()) {
    Serial.println("Could not find AHT? Check wiring");
    while (1)
      delay(10);
  }
  Serial.println("AHT10 or AHT20 found");


  //servo moteur 
  sg90.setPeriodHertz(50); // Fréquence PWM pour le SG90
  sg90.attach(PIN_SG90, 500, 2400); // Largeur minimale et maximale de l'impulsion (en µs) pour aller de 0° à 180°


  // MCP
  Serial.println("MCP23xxx Button Test!");

  // uncomment appropriate mcp.begin
  if (!mcp.begin_I2C()) {
    Serial.println("Error.");
    while (1);
  }

  // configure pin for input with pull up
  mcp.pinMode(BUTTON1_PIN, INPUT_PULLUP);
  mcp.pinMode(BUTTON2_PIN, INPUT_PULLUP);
  mcp.pinMode(BUTTON3_PIN, INPUT_PULLUP);
  mcp.pinMode(BUTTON4_PIN, INPUT_PULLUP);
  mcp.pinMode(BUTTON5_PIN, INPUT_PULLUP);
  mcp.pinMode(BUTTON6_PIN, INPUT_PULLUP);
  mcp.pinMode(BUTTON7_PIN, INPUT_PULLUP);
  mcp.pinMode(BUTTON8_PIN, INPUT_PULLUP);
  mcp.pinMode(BUTTON9_PIN, INPUT_PULLUP);
  mcp.pinMode(BUTTON10_PIN, INPUT_PULLUP);
  mcp.pinMode(BUTTON11_PIN, INPUT_PULLUP);
  mcp.pinMode(BUTTON12_PIN, INPUT_PULLUP);
  mcp.pinMode(BUTTON13_PIN, INPUT_PULLUP);
  mcp.pinMode(BUTTON14_PIN, INPUT_PULLUP);
  mcp.pinMode(BUTTON15_PIN, INPUT_PULLUP);
  mcp.pinMode(BUTTON16_PIN, INPUT_PULLUP);
  Serial.println("Looping...");

  // pin Enable MT3608 led / fan
  pinMode(32, OUTPUT);
  digitalWrite(32, LOW);

  //LED PWM
  pinMode(12, OUTPUT);
  pinMode(17, OUTPUT);

  // EC11
  pinMode(7, INPUT); // switch du EC11
  knob = new ESP_Knob(GPIO_KNOB_A, GPIO_KNOB_B);

    // knob->invertDirection();
    knob->begin();
    knob->attachLeftEventCallback(onKnobLeftEventCallback);
    knob->attachRightEventCallback(onKnobRightEventCallback);
    knob->attachHighLimitEventCallback(onKnobHighLimitEventCallback);
    knob->attachLowLimitEventCallback(onKnobLowLimitEventCallback);
    knob->attachZeroEventCallback(onKnobZeroEventCallback);

}

void loop() {
 
  //MUSIQUE 
  audio.loop();

 // VEML7700
 float lux = veml.readLux(VEML_LUX_AUTO);

  Serial.println("------------------------------------");
  Serial.print("Lux = "); Serial.println(lux);
  Serial.println("Settings used for reading:");
  Serial.print(F("Gain: "));
  switch (veml.getGain()) {
    case VEML7700_GAIN_1: Serial.println("1"); break;
    case VEML7700_GAIN_2: Serial.println("2"); break;
    case VEML7700_GAIN_1_4: Serial.println("1/4"); break;
    case VEML7700_GAIN_1_8: Serial.println("1/8"); break;
  }
  Serial.print(F("Integration Time (ms): "));
  switch (veml.getIntegrationTime()) {
    case VEML7700_IT_25MS: Serial.println("25"); break;
    case VEML7700_IT_50MS: Serial.println("50"); break;
    case VEML7700_IT_100MS: Serial.println("100"); break;
    case VEML7700_IT_200MS: Serial.println("200"); break;
    case VEML7700_IT_400MS: Serial.println("400"); break;
    case VEML7700_IT_800MS: Serial.println("800"); break;
  }

    //AHT20
  sensors_event_t humidity, temp;
  aht.getEvent(&humidity,
               &temp); // populate temp and humidity objects with fresh data
  Serial.print("Temperature: ");
  Serial.print(temp.temperature);
  Serial.println(" degrees C");
  Serial.print("Humidity: ");
  Serial.print(humidity.relative_humidity);
  Serial.println("% rH");

  //servo 
  for (int pos = 0; pos <= 180; pos += 1) {
    sg90.write(pos);
    delay(10);
  }


  // MCP BUtton
   // LOW = pressed, HIGH = not pressed
   if (digitalRead(7)==HIGH) {
    Serial.println("BTN du EC11 pushed");
    delay(50);
  }
  if (!mcp.digitalRead(BUTTON1_PIN)) {
    Serial.println("Button1 Pressed!");
    delay(50);
  }
   if (!mcp.digitalRead(BUTTON2_PIN)) {
    delay(50);
  }
  if (!mcp.digitalRead(BUTTON3_PIN)) {
    delay(50);
  }
  if (!mcp.digitalRead(BUTTON4_PIN)) {
    delay(50);
  }
  if (!mcp.digitalRead(BUTTON5_PIN)) {
    delay(50);
  }
  if (!mcp.digitalRead(BUTTON6_PIN)) {
    delay(50);
  }
  if (!mcp.digitalRead(BUTTON7_PIN)) {
    delay(50);
  }
  if (!mcp.digitalRead(BUTTON8_PIN)) {
    delay(50);
  }
  if (!mcp.digitalRead(BUTTON9_PIN)) {
    delay(50);
  }
  if (!mcp.digitalRead(BUTTON10_PIN)) {
    delay(50);
  }
  if (!mcp.digitalRead(BUTTON11_PIN)) {
    delay(50);
  }
  if (!mcp.digitalRead(BUTTON12_PIN)) {
    delay(50);
  }
  if (!mcp.digitalRead(BUTTON13_PIN)) {
    delay(50);
  }
  if (!mcp.digitalRead(BUTTON14_PIN)) {
    delay(50);
  }
  if (!mcp.digitalRead(BUTTON15_PIN)) {
    delay(50);
  }
  if (!mcp.digitalRead(BUTTON16_PIN)) {
    delay(50);
  }

  // led PWM 
  // exemple ici uniquement avec LEDA, LED B existe aussi 
  // increase the LED brightness
  for(int dutyCycle = 0; dutyCycle <= 255; dutyCycle++){   
    // changing the LED brightness with PWM
    analogWrite(LEDA, dutyCycle);
    delay(15);
  }

  // decrease the LED brightness
  for(int dutyCycle = 255; dutyCycle >= 0; dutyCycle--){
    // changing the LED brightness with PWM
    analogWrite(LEDA, dutyCycle);
    delay(15);
  }

  ShowHour(); // show hour and update every 1s with the delay 1000 bellow

  delay(1000);
}

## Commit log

2026-04-20 Create CAD
2026-04-21 Envoi propre des fichiers 3D avec LFS
    [Alarm_clock_blender.blend, Assemblage1 - back_box-1.STL, Assemblage1 - batterie 18650-1.STL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]
2026-04-21 Update README with power and current calculations
    Added calculations for current and power requirements for the light.
2026-04-22 Expand README with project component details
    Added details about components used in the project, including audio amplifier, battery protection, voltage regulation, PWM control for LEDs, light sensor, and connectors.
2026-04-22 Expand BOM section with component details and costs
    Added detailed breakdown of BOM components and costs, including images and notes on sourcing from LCSC and Aliexpress.
2026-04-24 Update features list in README
    Removed mention of battery from features list.
2026-04-30 Add STEP
    [STEP_full_box_components.STEP]
